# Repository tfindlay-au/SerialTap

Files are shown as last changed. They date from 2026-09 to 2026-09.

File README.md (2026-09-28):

# SerialTap

An open-hardware board that puts an appliance's 5 V serial service port on
Home Assistant. An ESP32-C3 with level translation, powered by the appliance
itself: one 4-wire cable carries 5 V, GND, TX and RX.

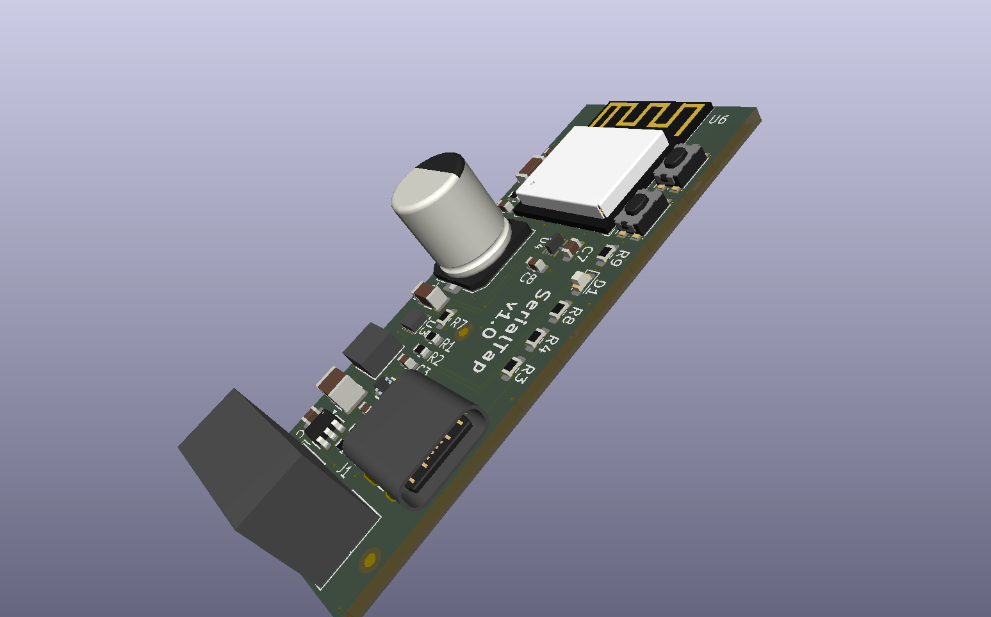
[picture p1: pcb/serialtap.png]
SerialTap v1.0, 3D render from KiCad


The reference target is a **Haier AS50QDFHRA** split-system air conditioner,
whose service port speaks GE Appliances **GEA3** at 230400 8N1
([docs/gea3.md](docs/gea3.md)). The board is not specialised to it: any
appliance exposing 5 V and a UART on a service connector is in scope.

## Status

**Version 1.0 has been sent to PCBWay; no board has been built yet.** The
`v1.0` tag marks the sources the order was built from.

Every design stage is done: power-path simulation, parts, library, schematic,
layout and three review gates. What is still owed is measurement on the real
appliance: the rail's current has so far been inferred, not measured
([ADR 0007](docs/adr/0007-rail-limit-inferred-not-measured.md)).

## The board

- **22 × 54 mm, 4-layer**, single-sided assembly, no mounting holes. It keeps
  the OEM module's outline and sits in its slot.
- **ESP32-C3-MINI-1** module. Programming and logs go over its built-in USB on
  a USB-C connector, so the appliance UART is never shared with logging.
- **Fixed-direction level translation** (TXU0204) between the 3.3 V module
  and the 5 V port, behind ESD protection and series resistors.
- **Power** from either the appliance or USB-C, ideal-diode OR-ed, through a
  current-limited eFuse and a 470 µF polymer bulk capacitor into a
  synchronous buck (TPS62162).

Service connector, as fitted to the reference appliance:

| Pin | 1 | 2 | 3 | 4 | 5 |
|---|---|---|---|---|---|
| Signal | 5 V | TX (board drives) | RX | spare (unknown) | GND |

## Where to start

| To understand… | Read |
|---|---|
| The vocabulary | [CONTEXT.md](CONTEXT.md) |
| The design, end to end | [docs/SPDD.md](docs/SPDD.md) |
| Why it is this way | [docs/adr/](docs/adr/): seven decisions, each with its context and what would reverse it |
| The protocol | [docs/gea3.md](docs/gea3.md) |
| How the schematic was checked | [docs/schematic-capture.md](docs/schematic-capture.md) |
| Layout rules and review gates | [docs/layout-rules.md](docs/layout-rules.md) |
| Parts and sourcing | [bom/README.md](bom/README.md) |
| Power-path simulation | [sim/README.md](sim/README.md) |
| Bring-up and measurement | [docs/bench-plan.md](docs/bench-plan.md), [docs/bench-results.md](docs/bench-results.md) |

## Repository layout

```
pcb/     KiCad 10 project: serialtap.kicad_sch / .kicad_pcb / .kicad_pro
lib/     the project's own symbols, footprints, 3D models and datasheets
sim/     LTspice power-path decks and their results
bom/     bill of materials and sourcing notes
docs/    design document, ADRs, protocol, layout and bench notes
bench/   capture and analysis scripts, and the ESPHome config used on the bench
```

## Opening and checking the design

Open `pcb/serialtap.kicad_pro` in **KiCad 10**. Everything it references is
in `lib/` through `${KIPRJMOD}`-relative paths, so it needs no global library.

```sh
CLI=/Applications/KiCad/KiCad.app/Contents/MacOS/kicad-cli   # macOS path
"$CLI" sch erc pcb/serialtap.kicad_sch
"$CLI" pcb drc --schematic-parity pcb/serialtap.kicad_pcb
```

The simulations need LTspice and vendor models that are not redistributed
here; [sim/README.md](sim/README.md) explains how to get them.

Fabrication outputs are regenerated rather than committed. Each fab order is
tagged, so a physical board traces back to its sources.

## Licence

Hardware under **CERN-OHL-P v2**; firmware and documentation under **MIT**.
Both are permissive. [NOTICE](NOTICE) sets out which files fall under which,
and the third-party material that falls under neither.

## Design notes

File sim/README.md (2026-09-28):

# Power-path simulation

Standalone LTspice decks, deliberately outside the KiCad flow
([SPDD §5.8](../docs/SPDD.md)). They model the **power path only**; nothing
else on the board has a usable model or a question worth simulating.

Simulation **gates fabrication** ([SPDD §12.1](../docs/SPDD.md) step 1). The
point is not a pass mark — it is a *number* to go and measure the appliance
against.

## Running

```sh
./models/fetch-models.sh   # once - vendor SPICE models (see below)
./run.py                   # every deck
./run.py rail-sag          # one deck
```

`run.py` drives `LTspice -b`, decodes the UTF-16 log it leaves behind, joins
each `.step` line to its `.meas` results and writes a table to
`results/<deck>.md`. Everything in `results/` is generated — re-run, never
edit. Stdlib Python only; no dependency outside this repo.

LTspice lives at `/Applications/LTspice.app/Contents/MacOS/LTspice`.

## The decks

| Deck | Question | State |
|---|---|---|
| `rail-sag.cir` | Given a current-limited source, bulk capacitance and WiFi transmit bursts, does the 5 V rail stay high enough for the buck to hold 3V3? | runs |
| `inrush.cir` | What does the appliance see at plug-in, with the eFuse limit set to a given value? | runs |
| `buck-load-step.cir` | Does the buck recover from a 40 → 335 mA step without undershooting brownout? | runs — **yes, with ~290 mV of margin** |

SPDD §5.4 quotes the step as 30 → 250 mA. Those are the **5 V-side** figures;
seen from the buck's output, where a load step actually happens, the same event
is 40 → 335 mA, which is what `buck-load-step` applies.

## The vendor models

### TPS62162 buck

`buck-load-step` is the one deck a behavioural block cannot answer — overshoot,
undershoot and settling belong to the control loop, the inductor and the output
capacitor together. It runs on TI's own model for the **TPS62162**.

`models/fetch-models.sh` downloads TI's *unencrypted* PSpice transient model
(literature number SLVMCV3) and converts it. Four things are worth knowing:

- **The vendor file is not committed.** TI ships it "as an aid for customers of
  Texas Instruments" with no redistribution grant, so the repo carries the fetch
  step and the converter instead of the file. This is the one exception to
  CLAUDE.md's "the project carries its own library" rule, and it is a licensing
  exception, not a convenience one — `lib/` still carries every KiCad asset.
- **One construct needed converting.** LTspice already understands PSpice's
  `VSWITCH` models, `TABLE {} = () ()` and `VALUE { IF(...) }` — all verified
  against this build before the converter was written. What defeats it is
  PSpice bracing a parameter reference *inside* a braced expression
  (`VALUE {{IF(V(A) > {VTHRESH}, {VDD},{VSS})}}`): the braces end up nested and
  LTspice reports "Questionable use of curly braces". `pspice2ltspice.py`
  strips the inner braces and passes everything else through untouched — 29
  expressions in this model.
- **`startup` on the `.tran` line is mandatory.** TI wrote the model for PSpice,
  which always solves an operating point first, so its internal latches and
  references need one. Plain `.tran` sends LTspice into minutes of Gmin
  stepping; `.tran ... uic` skips the operating point and the model sits dead,
  never switching. `startup` solves the operating point with the sources at
  zero — which converges immediately — then ramps them.
- **It is slow.** The model's soft-start runs about 1.5 ms and has to complete
  before a load step means anything, and a 2.2 MHz switcher is resolved
  throughout. Budget minutes per run and do not add sweeps casually. The `SS`
  subcircuit parameter looks like a way to skip soft-start — it is the initial
  condition on the ramp node — but setting it stops the model starting at all.
  Because a run is expensive, prefer `./run.py --keep-raw buck-load-step` when
  you might want to look at the waveform afterwards; the default throws the
  `.raw` away once the measurements are parsed out.

### Corrected result

Run 2026-09-20, on the TPS62162 model and Coilcraft's XGL4020-222 `_sat`
model, with no behavioural stand-ins in the power stage. The fixed-output
part's `FB` pin is tied to AGND, as required by the datasheet. This supersedes
the 2026-09-13 run, which left FB floating.

| COUT | regulated | undershoot on 40 → 335 mA | overshoot | margin to 3.0 V |
|---|---|---|---|---|
| 4.7 µF | 3.2994 V | 3.2846 V | 3.3107 V | **+285 mV** |
| 10 µF | 3.2994 V | 3.2905 V | 3.3099 V | +290 mV |
| 22 µF | 3.2994 V | 3.2926 V | 3.3074 V | +293 mV |

The corrected run passes with roughly 290 mV in hand at every capacitor value
tried.
Undershoot is 15 mV at worst — which is better than a 22 µF output capacitor on
a 295 mA step has any right to be, and implies the loop reacts within a switching
cycle or two. DCS-Control is genuinely that fast, but the model is TI's
behavioural one, so treat the absolute figure with suspicion. The conclusion
survives the doubt: the margin would have to be wrong by a factor of twenty
before this fails.

Going 22 µF → 4.7 µF costs 8 mV of
undershoot, so DC-bias derating cannot hurt us here: a 22 µF 0603 part that
derates to a third of its nameplate at 3.3 V still leaves the rail nowhere near
brownout. Size the output capacitor for ripple and stability, not for the load
step.

**The capacitor models in that deck are placeholders.** The converter is the
selected TPS62162 and the inductor is the selected XGL4020-222MEC. Re-run after
pinning the real input/output capacitor MPNs.

### PCL1A471MCL1GS bulk capacitor (C4)

`rail-sag` and `inrush` model C4 with **Nichicon's own model**, a 7-element RC
ladder (3.1 nH in series with three R–C branches totalling 475 µF). Nichicon's
engineering department supplied it on request with report FTR26-041,
2026-09-28. It replaced `CBULKX`, a lumped 470 µF with a flat 17 mΩ ESR.

- **Not committed, for the same reason as TI's.** It was sent to the project,
  not published for redistribution. `sim/.gitignore` already excludes
  `models/vendor/` and `models/*.lib`; `fetch-models.sh` documents the manual
  step and converts the CRLF line endings, which is the only conversion it
  needs — the model is plain L, R and C.
- **Checked against the datasheet before use**, by AC sweep:

  | | `CBULKX` (retired) | Nichicon model |
  |---|---|---|
  | \|Z\| at 120 Hz | 2.82 Ω | 2.79 Ω |
  | ESR at 100 kHz | 17 mΩ | **8.6 mΩ** |
  | ESR at 1 MHz | 17 mΩ | 7.7 mΩ |
  | Self-resonance | — | 159 kHz |

  The model's ESR is half the datasheet figure because 17 mΩ is the
  datasheet's *maximum*; the model is a typical part. So the old deck was
  conservative, not wrong. The model is small-signal, at 20 °C and 0 V bias;
  polymer capacitance barely moves with bias, so that is a fair basis.
- **It changes no result.** Run side by side on a 5 mA grid, the minimum
  appliance current is identical at every duty (110 / 170 / 245 mA), and
  `v5min` differs by at most 11 mV wherever both pass. Every `inrush` case
  passes or fails the same way. That is what the average-current finding below
  predicts: the capacitor's detail cannot move a number set by mean draw.
- **The decks run Gear integration because of it.** 3.1 nH over 6.6 mΩ is a
  ~0.5 ns time constant against a 10–20 µs step, and under LTspice's default
  trapezoidal method isolated steps came back with **all-zero measurements and
  no error in the log** — a false `NO` in the table. `method=gear` removes them
  and moves every other `v5min` by under 0.3 mV. If a row of zeros ever
  reappears, suspect the solver before the circuit.
- **The 220 µF / 1000 µF sweep was retired with `CBULKX`.** A vendor model is
  one part at one value. The sizing question it answered is settled below; the
  sweep is in git history if it is ever reopened.

## Model fidelity

`models/behavioral.lib` holds **behavioural** blocks, not vendor models. They
describe the terminal behaviour the datasheets promise over the timescales
these decks care about (~µs to ~1 s). Where a vendor model exists for the part
finally chosen, it replaces the block — as TI's has for the buck in
`buck-load-step`, and Nichicon's for C4 in `rail-sag` and `inrush`.

What they deliberately do not contain, and what therefore cannot be concluded
from these decks:

- **No switching.** The buck is a constant-power load, not a converter. Ripple,
  switching harmonics and EMI are not simulated here — EMC is
  `kicad-happy`'s job after layout.
- **No control loop.** The behavioural buck is a constant-power load with a
  UVLO, which is right for `rail-sag` and `inrush` and useless for a load-step
  question — hence `buck-load-step` running on the vendor model instead.
- **Instant limiter response.** `CLIM` reaches its limit in one timestep. A
  real TPS2553-class eFuse takes microseconds, so `inrush`'s `ispike` column
  understates the true contact event. Connector and cable inductance are not
  modelled either.
- **No temperature, no tolerance.** Every value is nominal at 27 °C. Tolerance
  is applied by hand when reading the results (see the eFuse arithmetic below).
- **Capacitance is a constant.** DC-bias derating is applied when choosing the
  parameter value (SPDD §7.1), not modelled as a function of voltage.

## What the decks found

Run 2026-09-12; **`rail-sag` and `inrush` re-run 2026-09-20** against the design
values in [SPDD §5.3](../docs/SPDD.md) — 470 µF bulk, ideal-diode OR, 0.95 Ω
total series resistance from appliance to rail.

> **Why they were re-run, and two defects found doing it.** Both decks were
> unrunnable in a clean checkout, so the tables below could not be reproduced.
>
> 1. `models/behavioral.lib` — which defines `CLIM`, `IDEALD`, `CBULKX` and
>    `BUCKLOAD`, every block `rail-sag` and `inrush` are built from — was
>    deleted by commit `786b8c3`, which moved `buck-load-step` onto vendor
>    models. The two behavioural decks still included it. `.gitignore` carries
>    an explicit `!/models/behavioral.lib` exception, so the deletion was
>    plainly accidental. Restored from history.
> 2. `rail-sag` set `RFUSE = 0.0` in commit `c5ce298` to record that no PTC is
>    fitted. **LTspice rejects a zero-ohm resistor outright**, so the deck has
>    been dead since 2026-09-13 and its committed results dated from *before*
>    the PTC was dropped. The parameter still reads 0.0 as the design
>    statement; the element is now `{max(RFUSE,1u)}`, and 1 µΩ is 0.25 µV at
>    250 mA.
>
> `ESRBULK` was also corrected from an assumed 25 mΩ to the **17 mΩ** the
> `PCL1A471MCL1GS` datasheet specifies at 100 kHz.
>
> **No conclusion reverses.** One cell of the table below moved, by 10 mA, and
> it strengthens the finding on bulk capacitance rather than weakening it. The
> 300–370 mA requirement is unchanged.

### The number: minimum appliance supply current

Minimum source current at which the 5 V rail stays above 4.0 V — the
placeholder for the buck's minimum input, `VBUCKREQ` in the deck:

| Radio duty | 220 µF | **470 µF** | 1000 µF |
|---|---|---|---|
| 20% — steady ESPHome traffic | 175 mA | **110 mA** | 110 mA |
| 50% — busy link | 200 mA | **175 mA** | 175 mA |
| 91% — association / OTA | 250 mA | **250 mA** | 250 mA |

**Sag is an average-current problem, not a peak-current one.** The knee sits
within ~10% of the mean draw in every case. Bulk capacitance rides out an
individual transmit burst; it cannot manufacture average current.

**And the answer barely depends on the buck.** `VBUCKREQ` is a reporting
threshold, not a modelling one, so the same results can be re-judged against a
different minimum input voltage without re-running. Dropping it from 4.0 V to
3.5 V — roughly dropout for the TPS62162 at this current, and well under any
candidate's UVLO — moves exactly one corner of the table (220 µF at 20% duty,
175 → 130 mA) and leaves every other figure unchanged. That is because the
failure mode is average-current starvation, which collapses the rail entirely
rather than dipping it marginally below a threshold. So the 300–370 mA
requirement stands whichever family member is finally chosen.

**This settles how much bulk is worth fitting.** Going 470 µF → 1000 µF buys
**nothing at any duty** — the two columns are now identical at every row.
Dropping to 220 µF costs 65 mA. 470 µF (SPDD §5.3) is the right size, and "add
more bulk" is *not* the answer if the Haier turns out marginal — more source
current is. (Before the 2026-09-20 corrections the 1000 µF column showed a
10 mA advantage at light duty; with the real capacitor's lower ESR that
advantage disappears.)

**Re-run 2026-09-28 on Nichicon's model for C4** (see "The vendor models"),
with the eFuse limit corrected to the fitted 400 mA (it read 600 mA) and
`inrush`'s `RFUSE` corrected to 0 Ω (it still carried the removed PTC's
0.2 Ω). The 470 µF column above is reproduced exactly — 110 / 175 / 250 mA —
and no `inrush` pass or fail moved. The 220 µF and 1000 µF columns are from the
retired lumped-capacitor sweep.

### The eFuse limit

`inrush` is unambiguous: the eFuse limit must sit **strictly below** the
appliance's own limit. Above it, the appliance is driven into its own current
limit and its rail is dragged down to follow the charging capacitor for the
whole ramp — 8–17 ms of an undefined state that may reset the appliance, which
is the failure [ADR 0004](../docs/adr/0004-current-limited-inrush.md) exists to
prevent.

Ramp time is just Q/I: 9.5 ms at 250 mA into 497 µF (C4's 475 µF plus the
ceramics), and the appliance is asked for a flat current for that whole time —
no peak beyond the limit itself.

`inrush` now also steps the **fitted** limit — `RILIM` = 66.5 kΩ, 351 / 400 /
449 mA across its tolerance. All three are polite to a 500 mA rail and none to
a 300 mA one, which is the rule above applied to the real part: this board
assumes the rail sources more than 449 mA. That is
[ADR 0007](../docs/adr/0007-rail-limit-inferred-not-measured.md)'s inference
from the ~590 mA the OEM module drew, not a new finding, and it is what the
series current measurement at bring-up will test.

Sizing, with `TOL` the chosen part's current-limit accuracy:

```
IEF_nom  ≥  sustained average draw / (1 - TOL)     so it never limits in service
IEF_nom  ≤  appliance limit / (1 + TOL)            so it always limits before
                                                    the appliance does
```

Taking the 246 mA sustained-transmit average from `rail-sag`:

| Limit accuracy | IEF nominal | Appliance must supply |
|---|---|---|
| ±10% | ≥ 273 mA | > 300 mA |
| ±20% | ≥ 308 mA | > 370 mA |

Which is the real headline: **the appliance needs 300–370 mA, not 250 mA**, if
the board is to both survive sustained transmit and stay polite at plug-in. The
figure firms up once the eFuse MPN — and with it `TOL` — is chosen.

### What to measure on the Haier

[SPDD §12.1 step 2](../docs/SPDD.md) now has numbers to test against:

1. Open-circuit voltage of the 5 V service rail.
2. **Current limit** — the one that matters. Pass is ≥ 370 mA; 250–300 mA means
   OTA and association on appliance power are at risk and the eFuse must be set
   below whatever the rail actually gives; under 250 mA the design needs
   rethinking, and not by adding capacitors.
3. Sag under a 250 mA pulsed load, to get `RAPP` — currently a 0.5 Ω guess.
4. Behaviour *in* current limit: does it fold back, latch off, or reset the
   appliance? The decks assume it merely droops.

## Parameters worth revisiting

| Parameter | Current value | Why it is a guess |
|---|---|---|
| `RAPP` | 0.5 Ω | Appliance source impedance. Measurement, item 3 above. |
| `RCABLE` | 0.25 Ω | ~1 m of 26 AWG out and back. Depends on the harness finally built. |
| `VBUCKREQ` | 4.0 V | Placeholder for the buck's minimum input. `margin` is `v5min - VBUCKREQ`, so results can be re-judged without re-running. |
| `RFUSE` | 0 Ω | No PTC is fitted; TPS2553 supplies the selected input protection. The deck represents 0 Ω as 1 µΩ because LTspice rejects an ideal zero-ohm resistor. |
| `TON` / duty | 2 ms, 20–91% | Transmit burst shape. Worst case is asserted, not measured. Worth a current probe during bring-up. |

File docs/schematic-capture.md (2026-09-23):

# Schematic capture contract — SerialTap

This is the wiring target for `pcb/serialtap.kicad_sch`. It records the
settled connectivity so schematic capture is a transcription and review task,
not another architecture discussion.

## Connector roles

J1 is the board-mounted JST XA service connector. The labels are from the
board's point of view:

| J1 pin | Net | Function |
|---:|---|---|
| 1 | `PORT_5V` | appliance 5 V input |
| 2 | `PORT_TX` | board output to appliance — the appliance's receiver |
| 3 | `PORT_RX` | appliance output to board — the appliance's transmitter |
| 4 | `PORT_NC` | deliberately unconnected until the harness investigation assigns it |
| 5 | `GND` | common return |

**Corrected 2026-09-20.** This table originally read 5 V, GND, TX, RX, spare at
pins 1–5, from a connector that was being read from the wrong end. Old pin *n*
is new pin *6 − n*. Direction is settled by the working TinyS3 rig, not
inferred: TinyS3 TX drives pin 2, pin 3 drives TinyS3 RX
([gea3.md](gea3.md)).

J2 is USB-C. All VBUS pins join `USB_VBUS`; all GND pins and shield join
`GND`; D+ and D− go through the USB ESD array to C3 GPIO19 and GPIO18.
CC1 and CC2 each receive a 5.1 kΩ pulldown to GND.

## Power tree

```text
PORT_5V ── TPS2553 IN
             TPS2553 OUT ── LM66200 IN1
USB_VBUS ────────────────── LM66200 IN2
                              LM66200 OUT ── V5
V5 ── TXU VCCB, bulk capacitor, buck VIN, power LED
TPS62162 VOUT ── V3V3 ── C3 VDD, TXU VCCA
```

TPS2553 `EN` is tied high to its input supply so the appliance branch is always
enabled. `FAULT` is brought to a labelled test pad or left as an explicitly
marked no-connect; `ILIM` receives the selected resistor to GND. There is no
PTC/resettable fuse. LM66200 provides the source isolation and TPS2553 provides
the port current limit and reverse blocking.

TPS62162 support wiring is fixed:

- `FB` → `AGND`
- `VOS` → `V3V3` at the output-capacitor positive terminal
- `AGND`, `PGND`, and exposed pad → `GND`
- `EN` → `V5`
- `PG` → labelled test pad (or explicit no-connect if not used by firmware)
- `SW` → XGL4020-222MEC → `V3V3`
- 10 µF ceramic from VIN to GND, 22 µF ceramic from V3V3 to GND, plus the 470 µF bulk on V5

## UART translation

The selected TXU0204RUTR is used as follows:

| TXU pin/function | Net |
|---|---|
| VCCA | `V3V3` |
| VCCB | `V5` |
| OE | `V3V3` |
| A1 input | C3 UART TX |
| B1Y output | `PORT_TX` through 330 Ω, 1% |
| B3 input | `PORT_RX` through 330 Ω, 1% |
| A3Y output | C3 UART RX |
| A2 and B4 inputs | tied to GND |
| A4Y and B2Y outputs | no-connect |
| GND and exposed pad | GND |

The TPD4E05U06QDQARQ1 channels are assigned to `PORT_TX`, `PORT_RX`, USB D+,
and USB D−. Its ground pin connects directly to GND. Each connector-facing
line reaches its ESD channel before the UART series resistor or USB trace.

## C3 support and recovery

- GPIO18 → USB D−; GPIO19 → USB D+
- GPIO9 has a 10 kΩ pull-up to V3V3 and BOOT switch to GND
- EN has a 10 kΩ pull-up to V3V3, RESET switch to GND, and reset capacitor to GND
- C3 receives local 100 nF and 10 µF V3V3 decoupling
- UART1 uses GPIO4 as TX and GPIO5 as RX; these are assigned to the TXU A-side nets

## Review invariants

- J1 pin 4 has no copper connection other than its own pad.
- No USB VBUS path can reach `PORT_5V` except through the LM66200 ideal-diode OR.
- The ESD array is ahead of both UART series resistors.
- `FB` is not floating; `VOS` senses at the output capacitor.
- Every unused TXU input is tied off and every unused output is explicitly no-connect.
- Every passive has an MPN before ERC/BOM review; values above are design values, not distributor substitutions.

## Capture record — 2026-09-20

Captured into [`pcb/serialtap.kicad_sch`](../pcb/serialtap.kicad_sch),
KiCad 10 native format (`version 20260306`), one A3 sheet in seven labelled
blocks: service port, USB-C, power path, level translation, ESP32-C3, test
access, ERC power sources. **43 components, 57 nets.**

`kicad-cli sch erc --severity-all` reports **0 violations**.

The connectivity above was transcribed and then checked against the *extracted
netlist*, not against the drawing — a drawing can look right and still be
wrong. Every review invariant, as `kicad-cli sch export netlist` reports it:

| Invariant | Netlist evidence |
|---|---|
| J1 pin 4 has no copper other than its own pad | `unconnected-(J1-Pin_4-Pad4)`, one node |
| No USB VBUS path to `PORT_5V` except through the OR | `USB_VBUS` = J2 VBUS ×4, C3, U2.VIN2. `PORT_5V` = J1.1, U1.IN, U1.EN, C1. They meet only at U2's output |
| ESD array ahead of both UART series resistors | `PORT_TX` = J1.2, **U5.D2+**, R1.1 — and `TX_BUF` = R1.2, U4.B1Y, TP4. Same shape for RX |
| `FB` not floating; `VOS` senses at the output capacitor | U3.5 (`FB`) is in `GND`; U3.6 (`VOS`) is in `V3V3` with C6 |
| Every unused translator pin handled | A2, B4 tied to `GND`; A4Y, B2Y carry explicit no-connects |
| Every passive has an MPN | **Not met** — see "Still open" below |

### Decisions taken at capture

- **`RILIM` = 66.5 kΩ 1% (R5).** TI's Table 2 row for a 400 mA nominal limit;
  with part and resistor tolerance the limit lands **351–449 mA**. That is
  ~100 mA above the board's 250 mA worst-case 5 V draw, so a Wi-Fi TX burst
  cannot nuisance-trip it, and below the ~590 mA inrush the rail demonstrably
  sources for the OEM module it was built to feed
  ([ADR 0007](adr/0007-rail-limit-inferred-not-measured.md)). The 88.7 kΩ /
  300 mA alternative was rejected: its 262 mA minimum leaves only 12 mA over
  the board's own estimated peak. Still an inferred value, to be confirmed at
  bring-up.
- **`FAULT`, `PG` and `ST` go to test pads** (TP8, TP9, TP10), not to GPIOs.
  Zero BOM cost, no firmware coupling. `FAULT` and `PG` are open-drain and
  carry pull-ups (R6 to `V5`, R7 to `V3V3`). The cost is that neither fault
  state is visible to Home Assistant; routing them to GPIO6/GPIO7 later is a
  respin, so this is the decision to revisit if remote fault reporting matters.
- **Drawing style: rails and cross-block signals by symbol and label, local
  topology by wire.** Power symbols (`PORT_5V`, `USB_VBUS`, `V5`, `V3V3`,
  `GND`) carry the rails; labels carry signals between blocks; wires are drawn
  where the topology is the point — the J1 → ESD → series resistor chain, the
  buck's SW node through L1, the BOOT and RESET networks, each pull-up. This
  keeps a 43-part board on one readable sheet. The netlist, not the drawing, is
  what was checked.
- **`LM66200` `VOUT_2` pin type changed to passive** in the project library.
  `VOUT_1` and `VOUT_2` are the same internal node, and two `power_out` pins on
  one net is an ERC conflict. The datasheet I/O column still says output; the
  library note records why the symbol departs from it.
- **Eleven generic symbols added to the project library** (R, C, LED, SW_Push,
  TestPoint, PWR_FLAG, GND, V5, V3V3, PORT_5V, USB_VBUS), copied from KiCad 10's
  own libraries so nothing references outside the repo. See
  [lib/README.md](../lib/README.md).

### Review gate 1 — kicad-happy, 2026-09-20

Run on the schematic alone; no PCB exists yet, so the cross-domain, EMC,
thermal and gerber analyses were **not run** and neither was the lifecycle
audit. 28 findings: 2 errors, 2 warnings, 24 informational.

| Finding | Verdict |
|---|---|
| `PP-001` U2.VIN1 has no DC path to a rail | **False positive.** `EFUSE_OUT` holds U1.OUT (`power_out`), U2.VIN1 and C2. The DC path runs through U1's pass FET; the rule walks the net graph only and cannot traverse an IC. A current-limited switch between two rails always trips it |
| `SS-001` BOM under 50% MPN coverage (9/21) | **True, and expected.** The passives are the open gate below |
| `DS-002` no `datasheets/` directory | **Path convention.** This project keeps vendor PDFs in `lib/datasheets/` beside the symbols that cite them |
| `UC-002` no ESD/TVS on VBUS at J2 | **Genuine, and accepted — not fitted** (decided 2026-09-20; see below and open item 2) |
| `PR-004` no series resistors on USB D+/D− | **Expected.** The C3's USB Serial/JTAG PHY needs none; Espressif's own boards fit none |

**The VBUS finding is worth a decision.** All four ESD channels are committed
(`PORT_TX`, `PORT_RX`, USB D+, D−), so VBUS is unprotected. `PORT_5V` is
covered by a different mechanism — the TPS2553 is rated 15 kV IEC 61000-4-2
*with external capacitance*, which C1 provides. VBUS has no equivalent: it
reaches the LM66200 directly, whose inputs are **6 V absolute maximum**
(datasheet §6.1) against a hot-plug transient that can overshoot well past
5.5 V. C3 (1 µF) damps it; nothing clamps it. A single-channel TVS on VBUS
would close this. Not fitted, because it is a new part and this project pins
parts deliberately rather than by reflex.

**Decided 2026-09-20, not to be reopened:** USB is used once, to flash the
board at setup — closer to a Tag-Connect pogo header than to a cabled port. The
risk is carried knowingly; see open item 2 below.

### Amended 2026-09-20: J1 pin numbering corrected

Captured first against the original table, then rewired when the connector was
found to have been read from the wrong end. The board-side nets are unchanged
— `PORT_TX` is still what the board drives — but they move pads: J1.2 now
carries `PORT_TX` through R1, J1.3 carries `PORT_RX` through R2, J1.4 is the
no-connect and J1.5 is ground. Confirmed in the netlist:

```
PORT_5V    J1.1 + C1.1 U1.1 U1.3
PORT_TX    J1.2 + R1.1 U5.4          TX_BUF  R1.2 + U4.10 (B1Y, output)
PORT_RX    J1.3 + R2.1 U5.5          RX_BUF  R2.2 + U4.8  (B3,  input)
unconnected-(J1-Pin_4-Pad4)
GND        J1.5 + ...
```

`TX_BUF` lands on the translator's B-side **output** and `RX_BUF` on its
B-side **input**, so the direction through the fixed-direction buffer matches
the rig that works.

### Amended 2026-09-21: TVS channels swapped for layout

`U5`'s four channels are identical, so which pair carries UART and which
carries USB is a layout choice, not an electrical one. With the array placed
under the USB-C pin row and the D± pair arriving from the module on the left,
the pair has to enter the **top** two pads or its descent crosses the UART
exits on L1. The labels were therefore swapped: **pins 1/2 (`D1±`) now carry
`USB_DP`/`USB_DM`, pins 4/5 (`D2±`) carry `PORT_TX`/`PORT_RX`.** The netlist
tables above are updated to match; ERC remains at 0 violations. No BOM change.

### Still open after capture

1. ~~**Passive MPNs.**~~ **Done 2026-09-20**, switches included — see
   [bom/README.md](../bom/README.md) and SPDD §7.4. Two capture defects surfaced
   while pinning them, both fixed: **C4 had been drawn with the generic `C`
   symbol** instead of its own `PCL1A471MCL1GS` symbol, which cost it an MPN, a
   footprint and — on a polarised polymer capacitor — its polarity marking; and
   **the ten test pads were appearing as a BOM line**, now excluded from the BOM
   while staying on the board as copper. Pinning the switches then changed a
   third thing: **R9 is 2.2 kΩ, not 10 kΩ**, so SW1's contacts carry 1.5 mA
   against C&K's 1 mA minimum (SPDD §7.4). R10 stays 10 kΩ.
2. ~~**VBUS TVS**~~ **Accepted, not fitted** (2026-09-20). The USB port is a
   one-off setup interface — the operational path is J1 — so the exposure is
   closer to a debug header's than to a permanently cabled port. The risk is
   real and recorded; the decision is to carry it.
3. **Reference designators are functional, not positional.** Re-annotate in
   KiCad if left-to-right ordering matters for the assembly drawing.

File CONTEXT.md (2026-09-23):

# Context: SerialTap

## What this project is

**SerialTap** is an open-hardware board that puts an appliance's 5 V serial
service port on Home Assistant. An ESP32 module plus bidirectional level
translation, powered by the appliance itself — one 4-wire cable carries 5 V,
GND, TX and RX.

Primarily a hardware design project: schematic and layout (KiCad 10),
gerbers, BOM, CPL and an assembly package for PCBWay. Scope also includes the
ESPHome package that runs on the returned boards and documented cable pinouts
per appliance, so that someone else can build one and fit it.

## Design principles

**1. Quality over cost.** This is not a race to the bottom on part count or
price. Where a branded part yields a better product, use it. Where extra
decoupling makes the circuit work better, add it. BOM cost on a five-board run
is dwarfed by assembly setup, shipping and time — and a marginal part that
forces one respin costs more than it ever saved.

Concretely: polymer or hybrid aluminium for bulk rather than generic
electrolytic; MLCCs chosen with DC-bias derating in mind, not just nameplate
capacitance; a shielded branded inductor with real saturation margin; genuine
JST parts, not clones.

**2. The design is not limited to KiCad's stock libraries.** Parts are chosen
for the design, and their symbols, footprints and 3D models are sourced from
SnapEDA or elsewhere as needed.

**3. The project carries its own library.** Everything the design depends on
lives in the repo, referenced with `${KIPRJMOD}`-relative paths, so the next
person can open it without having this machine's global library.

## Glossary

### SerialTap
The project and the board. Named for what it does: it taps an appliance's 5 V
serial service connector for **both data and power** over a single 4-wire cable.

Deliberately neutral about silicon and vendor — the module already changed once
mid-design (S3 → C3) and the reference appliance is only the first of many.

Previously named `esp32leveler`, where "leveler" meant *logic level translator*
and was routinely misread as a spirit level or inclinometer. That name is
retired; any surviving reference to it means this project.

### Level translator
The circuit that converts between the ESP32's 3.3 V logic and the target's 5 V
logic. Informally "level shifter"; use **translator** in schematic and doc text.
Never "leveler".

### Target device
The external equipment the board talks to over UART. It drives 5 V logic levels
and is the reason level translation exists at all.

### Board
The physical PCB design: the files `pcb/serialtap.kicad_*`. It has no revision
in its name — its version is a git commit, and a fab order is tagged so a board
in hand traces back to the commit it was built from.

### Port
The board's single level-translated UART channel, translated in both directions
with fixed-direction buffers.

Physically a **5-pin** JST XA connector (2.5 mm pitch), of which the design
uses four, in order **5 V, TX, RX, spare, GND**. It is simultaneously the data path to the
target device and the board's primary power source. There is exactly one port:
the board is a single-target adapter, not a multi-port gateway.

Five pins because that is what the reference target has. Confirmed 2026-09-12
on the AS50QDFHRA, mated with a JST **XARR-05V** panel housing — XA series,
2.5 mm pitch, contacts sold separately. The board therefore carries a 5-pin XA
header so the harness can be straight-through, which is the least error-prone
cable to build and to get wrong.

**What pin 4 does is unknown.** It read as floating on the capture — no
contact, or a genuine spare. Until that is settled it connects to nothing on
the board — not the ESD array, not a GPIO — because strapping an unknown signal
to a net that matters is a worse failure than losing a pin.

**The numbering was corrected on 2026-09-20**, having previously been read from
the wrong end of the connector: old pin *n* is new pin *6 − n*. Every document
in this repo now uses the corrected numbers.

### Primary supply
The 5 V arriving on the port's JST XA connector. The board is normally powered by
the target device it is controlling.

### Supply sources
Two, either of which may be live: the port's JST XA (primary) and USB-C (bench).
They are OR-ed with ideal diodes so neither can back-feed the other — in
particular so a laptop's USB cannot push 5 V into the target appliance's rail.

### Bench access
USB-C only. It carries first flashing (esptool over the C3's ROM USB
Serial/JTAG), ESPHome console logging over USB CDC, and OpenOCD debug. In
normal service the board is updated by ESPHome OTA and USB-C is unused.

### Recovery
BOOT (GPIO9) and RESET (EN) tact switches. Not needed for ordinary flashing —
esptool resets the chip into download mode over USB by itself — but the only
way back if firmware repurposes the USB pins, wedges the USB peripheral, or
boot-loops.

### Reference target
**Haier AS50QDFHRA** split-system HVAC. It speaks **GE Appliances GEA3** over
UART at 230400 8N1 — confirmed two-way on 2026-09-19 with an ESP32 running
the esphome-gea component, which returned 64 ERDs. It does *not* speak Haier
hOn or smartAir2, and ESPHome's built-in `haier` component does not apply.
The SPDD's firmware scope predates this and needs an ADR. See
[docs/gea3.md](docs/gea3.md).

It is the *reference* target, not the only one: it is what the first boards are
validated against and what the connector pinout is chosen to match.

### Generic use
The board is intended to work with any appliance exposing 5 V power and UART on
a service connector. Nothing in the hardware may assume Haier specifically — no
protocol-dependent circuitry, no reliance on a particular idle level, and no
assumption about how much current the appliance's 5 V rail can supply.

### Port pinout
Fixed, not selectable. Conventional order **5 V, GND, TX, RX**, silkscreened
from the *board's* point of view: TX is the pin the board drives, RX is the pin
the board listens on.

There is no crossover jumper. Because the translators are fixed-direction
(see ADR 0001), a polarity mistake cannot be corrected in firmware either —
remapping the C3's UART pins would drive a buffer backwards. Adapting to an
appliance that orders or labels its pins differently is a **cable** problem, and
each appliance gets a documented harness.

## Resolved design decisions

| Area | Decision |
|---|---|
| Module | ESP32-C3-MINI-1 (ADR 0002) |
| Port | One, JST XA **5-pin**, four used: 5 V, TX, RX, (spare), GND |
| Translation | Fixed-direction dual-supply buffers (ADR 0001) |
| Supply sources | JST XA 5 V (primary) and USB-C, ideal-diode OR-ed |
| Inrush / sag | Current-limited eFuse + ≥470 µF low-ESR bulk (ADR 0004) |
| 3.3 V rail | Synchronous buck, not an LDO (ADR 0003) |
| Port protection | Series resistors on TX/RX; one quad ESD array protects both UART lines and USB D+/D−; TPS2553 protects the port 5 V input |
| Programming | USB-C only; BOOT (GPIO9) and RESET (EN) tact switches |
| Source of truth | KiCad 10 schematic → netlist → PCB (ADR 0005) |
| Parts | Every component pinned by MPN; no automatic part picking |
| Library | Project-local `lib/`, `${KIPRJMOD}`-relative, nothing global |
| Mechanical | Bare board, mounting holes, no enclosure |
| Stackup | 4-layer: L1 sig+parts / L2 GND / L3 rails / L4 GND |
| Outline | 22 × 54 mm; JST on one short edge, USB-C on the adjacent long edge, antenna at the far short edge |
| Fab class | PCBWay 5/5 mil, 0.2 mm drill (0.25 mm until 2026-09-24); impedance not controlled |
| Indicators | Power LED only; no status or activity LEDs |
| Test points | Pads on 5 V, 3V3, GND, and both sides of each translator channel |
| First run | 5 boards, single-sided assembly (all parts on top) |
| Scope | Hardware + ESPHome package + harness documentation |
| Licence | CERN-OHL-P for hardware, MIT for firmware and docs |
| Simulation | Power path only, LTspice decks in `sim/`, gates fabrication |
| Board acceptance | Loopback plug + ESPHome self-test, per board |

### Hot loop
The buck's input loop — input ceramic → high-side FET → low-side FET → ground →
back to the ceramic. It carries the fastest di/dt on the board and is the
dominant EMI source. Minimising its area outranks every other layout
consideration except the antenna keepout.

Distinct from the **switch node**, which is the dV/dt aggressor and is
deliberately kept small in *area* rather than poured.

### Project library
`lib/` at the repo root: symbols, footprints and 3D models for every part in the
design, plus datasheets. Referenced by the KiCad project in `pcb/` with
`${KIPRJMOD}`-relative paths.

Nothing in the design may depend on a library outside this directory.

### Simulation deck
A standalone LTspice netlist in `sim/`, hand-written and deliberately outside
the KiCad flow. Decks model the power path only; nothing else
on the board has a usable model or a question worth simulating.

### Loopback plug
A JST XA shell with TX bridged to RX. Turns the whole signal chain into a
self-test: firmware transmits a pattern and checks it returns, exercising both
translation directions, both series resistors and the connector, with no scope
and no appliance. It does not prove drive strength into a loaded line.

### Build artifact
Anything produced by `kicad-cli` from the design files: gerbers, drill files,
the BOM and CPL, the schematic PDF, STEP and image renders. These live under
`pcb/fab/` (gitignored until release) and are never hand-edited — regenerate them instead.

The design files themselves — `.kicad_sch`, `.kicad_pcb`, `.kicad_pro` — are
**not** build artifacts. They are drawn and maintained by hand, and they are the
source of truth (ADR 0005). Nothing generates them, which is why there is no
rule against editing them.

## Known risks

- **Weak appliance rail.** The Haier 5 V service output is current-limited and
  its capability is not yet measured. Mitigated by the buck (≈250 mA peak draw
  versus ≈335 mA for an LDO), soft start, and bulk capacitance — but the actual rail must be
  measured during bring-up before the design is considered validated.
  Simulation (`sim/`, 2026-09-12) says it needs to supply **300–370 mA**, and
  that bulk capacitance cannot substitute for source current: sag is set by the
  *average* draw, so the capacitor rides out one transmit burst and nothing
  longer.
- **Bare board in an appliance.** No enclosure means exposed electronics near
  HVAC condensate and mains wiring. Accepted deliberately; the board is not
  weather- or touch-protected, and any production use would need one.
- **No SPICE model for the buck or eFuse.** Simulation gates fabrication, so a
  part without a usable vendor model cannot be used regardless of price or
  availability. This constrains selection before a part is committed.
- **Silent substitution at assembly.** Every part is pinned by MPN precisely so
  that a cheaper equivalent cannot reach the board unnoticed. Substitutions must
  be proposed back for a decision, never applied silently.
- **Protocol — resolved.** The port speaks GEA3, which GE publishes
  (tiny-gea-api) and for which an ESPHome component exists (esphome-gea).
  Decoded 2026-09-18, confirmed two-way 2026-09-19, recorded in
  [ADR 0006](docs/adr/0006-gea3-not-hon.md) with the ERD map in
  [docs/gea3.md](docs/gea3.md). No hardware consequence; it *validates*
  ADR 0001, because GEA3 is full duplex with a fixed direction per line.
  Remaining work is firmware only: which ERD carries which control, the ten
  ERDs GE's public set does not name, and ERD `0x6003`.
- **Rail capability — inferred, not measured.** The resistor load test no longer
  gates fabrication; `RILIM` is set from inference instead
  ([ADR 0007](docs/adr/0007-rail-limit-inferred-not-measured.md)). What that
  gives up is written down there, along with the conditions that reinstate the
  test. The unexplained manual reset on first power-up from the rail is the one
  open item that could still change the design.
- **Unverified Haier pinout.** ~~Partly resolved.~~ **Resolved 2026-09-20,
  except for one pin.** The *connector* was confirmed on 2026-09-12: a 5-pin
  JST XA, 2.5 mm pitch, mated with an XARR-05V panel housing. The *pin order*
  is now settled — 5 V, TX, RX, spare, GND — after the numbering was found to
  have been read from the wrong end; direction comes from the working TinyS3
  link rather than inference. **Pin 4's function remains unknown**, which holds
  up nothing but the harness documentation.

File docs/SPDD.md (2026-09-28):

# Software & Product Design Document — SerialTap

**Status:** draft, pre-schematic
**Date:** 2026-09-12
**Licence:** CERN-OHL-P v2 (hardware), MIT (firmware and documentation)

Terminology for this project is defined in [CONTEXT.md](../CONTEXT.md).
Decisions with lasting consequences are recorded in [docs/adr/](adr/).

---

## 1. Purpose

A small PCB that lets an ESP32 speak UART to appliances whose serial ports use
5 V logic, and be powered by those same appliances over the same connector.

The immediate motivation is putting a **Haier AS50QDFHRA** split-system HVAC on
Home Assistant via ESPHome's `haier` component. The board is deliberately not
specialised to it: any appliance exposing 5 V, GND, TX and RX on a service
connector is in scope.

The name describes the mechanism: one 4-wire cable **taps** the appliance's
service connector for both data and power. It is deliberately neutral about
silicon and vendor — the module changed once during design and the reference
appliance is only the first of many.

Formerly `esp32leveler`, where "leveler" meant *level translator* and was
consistently misread as a spirit level.

## 2. Scope

**In scope**

- Schematic and PCB design (KiCad 10)
- Fabrication and assembly package for PCBWay: gerbers, drill, BOM, CPL
- A firmware package that runs on the assembled board, ESPHome by default
- Harness documentation: cable pinouts per appliance, starting with the Haier

**Out of scope**

- Any enclosure. The board ships bare (§8).
- Reverse engineering an appliance protocol from scratch. The reference
  appliance speaks **GEA3**, which is public and has both a portable C library
  and an existing ESPHome component ([ADR 0006](adr/0006-gea3-not-hon.md)).
  Mapping which ERD carries which control is observation, and is in scope.
- Certification, EMC testing, or commercial production

## 3. Functional requirements

| # | Requirement |
|---|---|
| FR-1 | Provide one bidirectionally level-translated UART channel between the ESP32's 3.3 V logic and a target's 5 V logic |
| FR-2 | Accept 5 V from the target on the same connector as the data lines, and run the whole board from it |
| FR-3 | Operate reliably at 230400 8N1 (the reference target's measured rate, [ADR 0006](adr/0006-gea3-not-hon.md)) and impose no design ceiling below 1 Mbaud |
| FR-4 | Be flashable from a bare, unprogrammed state over USB-C with no jig or external adapter |
| FR-5 | Be recoverable by hand if firmware renders USB unusable |
| FR-6 | Never source current into a target appliance's rail from a bench supply, or vice versa |
| FR-7 | Survive ordinary installation faults on the port: ESD, hot-plug, a line shorted to 5 V or GND |
| FR-8 | Support ESPHome OTA as the normal update path once first-flashed |

## 4. Architecture

**Signal path**

```
  JST XA          ESD    series R  fixed-direction        ESP32-C3-MINI-1
  TX ------------[ ]-----[ Rs ]---[ B->A translator ]----> RX  (UART1)
  RX ------------[ ]-----[ Rs ]<--[ A->B translator ]----- TX  (UART1)
                                  VCCB=5V  VCCA=3V3

                                   USB-C  D+/D- <-------> GPIO18/19
                                                  (ROM USB Serial/JTAG:
                                                   flashing, CDC log, debug)
```

**Power path**

```
  JST XA 5V ---------[ eFuse ]--[ideal diode]--+
                    (current-limited, bounds inrush) |
                                                +-- 5V rail --+-- [470uF+]
  USB-C VBUS ---------------------[ideal diode]-+              |
                                                               +-- [PWR LED]
                                                               |
                                                               +-- VCCB
                                                               |
                                                        +------+------+
                                                        | sync buck   |
                                                        |  5V -> 3V3  |
                                                        +------+------+
                                                               |
                                                        3V3 rail --> C3, VCCA
```

**Signal path.** Target ↔ ESD array ↔ series resistors ↔ fixed-direction
translators ↔ C3 UART1. Console and debug ride the C3's built-in USB
Serial/JTAG on GPIO18/19, out to USB-C, so the port's UART is never shared with
logging.

**Power path.** The JST 5 V and USB-C VBUS are each ideal-diode OR-ed onto a
common 5 V rail; a current-limited eFuse limits inrush; a synchronous buck
produces 3.3 V.

## 5. Detailed design

### 5.1 Level translation

Two fixed-direction dual-supply buffer channels — one 3.3 V → 5 V for TX, one
5 V → 3.3 V for RX — with direction hard-wired in copper. Rationale and the
rejection of auto-direction parts (TXB/TXS) is in
[ADR 0001](adr/0001-fixed-direction-level-translation.md).

VCCA is the 3.3 V rail; VCCB is the 5 V rail. Unused translator inputs are tied
off, never left floating.

Consequence to keep in mind: direction is frozen. Half-duplex or single-wire
buses are out of reach for this board without a revision.

### 5.2 Port and pinout

One JST XA **5-pin** connector (2.5 mm pitch), four of which are used, in fixed
pin order **1 = 5 V, 2 = TX, 3 = RX, 4 = spare, 5 = GND**, silkscreened from
the board's point of view — TX is the pin the board drives, which is the
appliance's receiver.

**This order is corrected as of 2026-09-20.** Earlier revisions of this
document, the bench notes and `gea3.md` numbered the connector from the wrong
end and read 5 V, GND, TX, RX at pins 1–4. Nothing measured changed; the
labels did. Direction is not inferred: on the working TinyS3 rig the shifter
carries TinyS3 TX into pin 2 and pin 3 into TinyS3 RX
([gea3.md](gea3.md)).

The pin count follows the reference target: the AS50QDFHRA service connector
was confirmed on 2026-09-12 to be a 5-pin XA, mated with a JST XARR-05V panel
housing. Carrying five on the board keeps the harness straight-through.

Board-side candidates, all XA series, 2.5 mm pitch, 5 position:

| MPN | Entry |
|---|---|
| `B05B-XASK-1(LF)(SN)` | vertical, top entry, shrouded |
| `B05B-XASK-1-A(LF)(SN)` | vertical, with locating boss |
| `S05B-XASK-1(LF)(SN)` | right angle, side entry |

Not yet pinned: entry direction is a mechanical call about how the board sits in
the appliance, and the gender/mating relationship against XARR-05V should be
read off the JST XA datasheet rather than a distributor summary before an MPN
is committed.

**Pin 4's function is unknown** — it read as floating, either no contact or a
genuine spare — so nothing on the board connects to it: not the ESD array, not
a GPIO. Committing it to anything before it is known risks strapping an unknown
signal, possibly not a 5 V-logic one, to a net that matters.

There is no crossover jumper, and the C3's GPIO matrix cannot substitute for
one: remapping UART pins would drive a fixed-direction buffer backwards.
Appliances that order or label their pins differently are accommodated by a
**cable**, documented per appliance.

### 5.3 Power

| Element | Choice |
|---|---|
| Sources | JST XA 5 V (primary), USB-C VBUS (bench) |
| Arbitration | Ideal-diode OR on each source (LM66100 / MAX40203 class) |
| Inrush | Current-limited switch / eFuse (TPS2553 class), programmable limit ([ADR 0004](adr/0004-current-limited-inrush.md)) |
| Bulk | ≥470 µF low-ESR on the 5 V rail, plus local ceramics |
| 3.3 V | Synchronous buck ([ADR 0003](adr/0003-buck-not-ldo.md)) |
| Fusing | **None.** TPS2553 provides constant-current limiting, thermal shutdown and reverse blocking, which is stronger and faster than a PTC's thermal trip. A PTC would only add cover for the eFuse itself failing short, and would cost 0.2–0.5 Ω in series — ~75 mV at 250 mA on a rail with no headroom to spare. Recorded as a deliberate removal, not an omission (ADR 0004 anticipated this) |

Ideal diodes rather than Schottkys because ~20 mV of drop keeps the 5 V rail
genuinely at 5 V for the translators' VCCB, and because a laptop must never be
able to push current into an appliance's rail (FR-6).

### 5.4 Power budget

| Condition | 3.3 V draw | 5 V draw (buck, ~90%) |
|---|---|---|
| Idle, WiFi connected | ~40 mA | ~30 mA |
| WiFi RX / normal traffic | ~85 mA | ~65 mA |
| WiFi TX peak (20 dBm) | ~335 mA | ~250 mA |

The Haier's 5 V service rail capability is **not yet measured**. Simulation
(§5.8) establishes the minimum the design needs; measurement (§12) confirms the
appliance provides it. Both gate fabrication.

### 5.5 Programming and recovery

USB-C is the only programming, logging and debug interface
([ADR 0002](adr/0002-c3-and-usb-only-programming.md)). A virgin C3 enumerates on
its ROM USB Serial/JTAG and esptool drives it into download mode unaided, so
first flash needs no buttons.

BOOT (GPIO9) and RESET (EN) tact switches exist for the cases where that fails:
firmware repurposing GPIO18/19, a wedged USB peripheral, a hard boot-loop.

No TC2050 footprint. The ESP32-C3 has no external JTAG pins, so a pogo footprint
would carry the same USB pair as the USB-C connector and add nothing.

### 5.6 Protection

- **330 Ω, 1% series resistors** on TX and RX, selected from the powered-down
  appliance RX bias measurement. They limit fault current if a line meets 5 V
  or GND during install.
- The single four-channel ESD array protects the two JST UART signals and USB
  D+/D−. The interfaces are not used concurrently, but this assignment protects
  either interface from an accidental cable connection without another device.
- Port 5 V current limiting and reverse blocking are provided by TPS2553;
  source isolation is completed by the LM66200 ideal-diode OR.

### 5.7 Indicators and test access

One power LED, high-value resistor. No status LED and no TX/RX activity LEDs —
serial traffic is observable through ESPHome's own logging, which makes
dedicated hardware indicators redundant.

Test pads on 5 V, 3V3, GND, and **both the 3.3 V and 5 V side of each translator
channel**. These are bare copper at zero BOM cost and are what make ADR 0001's
"don't debug translation after assembly" argument actually hold.

### 5.8 Simulation

Simulation is scoped to the **power path only** and gates fabrication.

Nothing else on the board benefits. The C3-MINI-1 has no SPICE model — its
relevant behaviour is a pulsed current source. The translators ship as IBIS, not
SPICE, and answer signal-integrity questions that do not exist at 9600 baud over
a short harness; the translator question that does matter (drive strength into
an unknown appliance's pull-ups) is a DC calculation.

Three decks in `sim/`:

| Deck | Question it answers |
|---|---|
| `rail-sag` | Given a current-limited source, bulk capacitance and a 250 mA WiFi burst, does 3.3 V stay above the C3's brownout threshold? Swept across source current limit. |
| `inrush` | What does the appliance see at plug-in, with the eFuse limit set to a given value? |
| `buck-load-step` | Does the buck recover from a 30 → 250 mA step without undershooting brownout? |

`rail-sag` is the important one. Its output is not "it works" but a **number**:
the minimum source current this design tolerates. That converts the project's
largest unknown from a blocker into a specification to go and measure against,
and quantifies what extra bulk capacitance would buy if the Haier falls short.

**Status (2026-09-12).** `rail-sag` and `inrush` are written and run; results
and the numbers they produced are in [sim/README.md](../sim/README.md). In
short: sag is an average-current problem, so 470 µF is the right bulk value and
adding more would not rescue a weak rail; and the eFuse limit must sit strictly
below the appliance's own limit, which puts the appliance requirement at
**300–370 mA**, not the 250 mA of §5.4.

`buck-load-step` uses the TPS62162 vendor model, because its question is about
the converter control loop and cannot be answered by a behavioural block. The
corrected 2026-09-20 deck ties the fixed-output part's `FB` pin to AGND and
passes the 40 → 335 mA load step with at least 285 mV margin to 3.0 V. Results
are in [sim/README.md](../sim/README.md).

**2026-09-28:** `rail-sag` and `inrush` now model the bulk capacitor with
Nichicon's own model for the PCL1A471MCL1GS, supplied on request, and use the
fitted 400 mA eFuse limit. Every result is unchanged. The model's typical ESR
is 8.6 mΩ against the datasheet's 17 mΩ maximum, which confirms the part.

Simulation lives **outside** the KiCad flow. KiCad 10's built-in ngspice can
simulate a schematic, but the questions here are about a power path that spans
an appliance, a cable and a converter — most of which is not on the board and
has no symbol. The decks are standalone SPICE netlists, which also keeps them
readable and diffable on their own terms.

**Simulator: LTspice.** Homebrew cannot build ngspice on this machine — macOS
12.7.6 is past Homebrew's support window, and `brew install ngspice` fails
trying to compile gcc from source. KiCad bundles `libngspice` as a shared
library with no CLI. LTspice is a native macOS download, needs no toolchain, is
auto-detected by `kicad-happy`'s `spice` skill, and is the format many vendors
publish their models in — which matters given §7.1 requires parts with published
SPICE models.

## 6. Toolchain

**KiCad 10 is the single source of truth**: schematic → netlist → PCB, the
standard flow, with ERC built in. This reverses the original decision to make
atopile the source of truth and reduce KiCad to layout. The reasoning, the
evidence gathered by actually running the tools, and the three
code-to-schematic generators evaluated and rejected are in
[ADR 0005](adr/0005-kicad-native-capture.md).

| Artefact | Owner | Hand-edited? |
|---|---|---|
| `*.kicad_sch` | KiCad 10 | **Yes — this is the source.** Capture lives here |
| `*.kicad_pcb` | KiCad 10 | Yes — netlist updated from the schematic |
| `*.kicad_pro` | KiCad 10 | Yes — carries the DRC rules and net classes from [layout-rules.md](layout-rules.md) |
| netlist | `kicad-cli sch export netlist` | No |
| gerbers, drill | `kicad-cli` | No |
| BOM | `kicad-cli sch export bom` | No |
| `-sch.pdf` | `kicad-cli sch export pdf` | No |
| `sim/*.cir` | hand-written | Yes — standalone, outside the KiCad flow (§5.8) |

Nothing among the design files is generated, so nothing can be silently
regenerated over — which is why there is no "never hand-edit this" rule any
more. The checks are mechanical instead: `kicad-cli sch erc` and
`kicad-cli pcb drc`, both of which run today.

**Review tooling.** `kicad-happy` (v2.2.1, MIT) is installed as a Claude Code
plugin and reviews the `.kicad_sch` and `.kicad_pcb` directly. A hand-drawn
schematic is precisely the artifact it was built to read, and having one is what
makes the first review gate (§12.1) possible at all.

## 7. Components and sourcing

### 7.1 Component quality policy

The design optimises for a *balanced* product, not a minimal BOM. Where a
branded part yields a better result, it is used. Where extra decoupling improves
behaviour, it is added.

Specific consequences on this board:

| Part | Policy |
|---|---|
| Bulk capacitor | Polymer or hybrid aluminium (Panasonic, Nichicon, Würth), not generic electrolytic. The reason is **no dry-out** in a warm appliance, *not* ESR — the load step needs only 185 mA, so even 200 mΩ would cost 37 mV. Do not pay for exotic ESR here |
| MLCCs | Chosen with **DC-bias derating** accounted for. A 10 µF 0603 6.3 V X5R can lose most of its capacitance at 5 V; use larger case sizes and 16–25 V ratings so the nameplate value is close to the real one |
| Inductor | Shielded, branded (Coilcraft, Würth, TDK, Bourns), with genuine saturation margin over the peak — and a published SPICE model (§5.8) |
| Buck, eFuse, ideal diodes | Branded silicon with vendor SPICE models and real datasheets |
| TVS array | Purpose-made ESD protection array (Nexperia, Semtech, onsemi), not a generic diode |
| Connectors | Genuine JST XA and a branded USB-C receptacle with through-hole retention |
| Decoupling | Added generously. Both VCCA and VCCB on every translator, multiple values at the module, bulk plus ceramics on every rail |

### 7.2 Sourcing

**Every component is pinned by MPN on its schematic symbol, passives included.**
There is no automatic part picker in this flow — removing atopile removed the
one that had to be suppressed anyway (ADR 0005). A substitution reaching the
board without a decision having been made is the failure mode being designed
against, and the defence is now review rather than configuration.

The exported BOM carries MPN plus LCSC and Digi-Key/Mouser numbers, and PCBWay
sources from whichever it can. Substitutions are proposed back, never applied
silently.

**Additional selection criterion:** because simulation gates fabrication (§5.8),
the **buck** must be a part whose vendor publishes a usable SPICE model. TI and
ADI generally do; several cheaper LCSC-catalogue alternatives do not — including
the AOZ1280CI on `daikin-esp`'s `esp-daikin-r1p1`, which is why that part is not
simply carried over. This applies before the buck is committed to the design.

The criterion does **not** extend to the eFuse. Its deck's question is answered
by the current limit alone, which a behavioural block models exactly; requiring
a vendor model there would narrow the field for nothing. Reasoning and
consequences are in the 2026-09-12 amendment to
[ADR 0004](adr/0004-current-limited-inrush.md) — in exchange, the eFuse's
current-limit *accuracy* becomes a first-order selection criterion, because it
is what sets the appliance requirement.

### 7.4 Parts register

Filled in as parts are pinned. Every entry is a decision with a reason, not a
search result. Until the schematic exists this is the record; afterwards the
schematic symbols carry the MPNs and this table points at the reasoning.

| Function | MPN | Why this one |
|---|---|---|
| 3.3 V buck | **TPS62162DSGT** (WSON-8, 2×2 mm; `T` = 250-piece reel) | Fixed 3.3 V, so no feedback divider. `FB` is tied to AGND and `VOS` senses at the output capacitor, per the datasheet; the latter remains a control-loop-sensitive layout net. 1 A against a 335 mA peak. The only candidate with both a fixed output *and* an unencrypted SPICE model — TPS6282533 has no published model, TPS62901's is 74% Cadence-encrypted. Costs ~2 efficiency points against the TPS6282x, worth ~5 mA of appliance current, which is noise against a 300–370 mA requirement ([ADR 0003](adr/0003-buck-not-ldo.md), §5.8) |
| Buck inductor | **XGL4020-222MEC** (Coilcraft) | 2.2 µH, 19.5 mΩ DCR against the XFL3012's 97 mΩ — buys back ~0.8 of the ~2 points conceded above. Isat 2.7 A sits clear of the IC's ~1.6–2 A current limit, so the IC protects before the inductor saturates. Coilcraft publishes a `_sat` LTspice model, verified against the datasheet before use. 2.0 mm tall, confirmed to clear the enclosure |
| Port connector | **B05B-XASK-1-A(LF)(SN)** (JST XA, 5-pin, vertical, with boss) | Matches the appliance's XARR-05V panel housing, so the harness is straight-through (§5.2). Vertical entry confirmed against the enclosure. `-A` for the boss: this is the board's only permanent mechanical interface and takes every insertion force in a unit that vibrates, so the boss carries that into the board rather than the solder joints. Tin, not `-GU` gold — plating should match across a mating pair, and standard XA crimps are tin. **Through-hole**, so it needs a selective- or hand-solder step on an otherwise all-SMD board |

| Level translator | **TXU0204RUTR** (`RUT` UQFN-12, 2.0 × 1.7 mm) | 4-bit fixed-direction, two channels each way — TI names UART as the application. Direction fixed in *silicon*, so there is no DIR pin to mis-strap; Schmitt-trigger inputs for a metre of harness; integrated pull-downs, which retire ADR 0001's own warning about floating unused inputs. Push-pull ±12 mA at 4.5 V against the ~4 kΩ of the auto-direction parts ADR 0001 rejected. Two channels unused. See the 2026-09-13 amendment to [ADR 0001](adr/0001-fixed-direction-level-translation.md) |

| eFuse | **TPS2553DBVR** (SOT-23-6) — **not the `-1`** | ADR 0004's part. 75 mA–1.7 A adjustable limit, 2.5–6.5 V, 85 mΩ, active-high enable, **reverse blocking**, thermal shutdown, constant-current limiting rather than latch-off (the `-1` suffix latches; we do not want that). Unencrypted PSpice model exists, though ADR 0004's amendment means one is not required here. `R<sub>ILIM</sub>` is selected from the inferred rail envelope under ADR 0007, then checked at bring-up. |
| Ideal-diode OR | **LM66200DRLR** (SOT-5X3-8, its only package) | 1.6–5.5 V, 40 mΩ, 2.5 A, low I<sub>Q</sub>, **two ideal diodes in one package** — both OR branches in a single part instead of two LM66100s. Unencrypted PSpice model |

| ESD array | **TPD4E05U06QDQARQ1** (TI, AEC-Q101) | Quad, 0.5 pF, V<sub>RWM</sub> 5.5 V, min breakdown 6.5 V, ±12 kV, 2.5 A / 40 W surge. Channels protect JST TX/RX and USB D+/D−; the ports are mutually exclusive in normal use, but both remain protected against an accidental cable connection. The `-Q1` is taken for its temperature grade, not automotive compliance — this board lives in a warm appliance with no enclosure. **Caveat:** 5.5 V standoff against 5 V logic is 0.5 V of margin, so the Haier's open-circuit rail voltage must be confirmed (already on the bench list) |
| USB-C receptacle | **USB4085-GF-A** (GCT) | USB 2.0, 16 contacts, through-hole, horizontal top-mount, four PCB retention/grounding posts, 10 000 mating cycles, 3.46 mm profile. Through-hole retention is what §7.1 asked for, and it shares the selective-solder step the JST already needs. **KiCad 10 ships both a reviewed footprint and a STEP model** for it, which is not true of any vertical receptacle. Vertical was considered: it would free ~9 mm of long edge we do not need, in exchange for the cable levering perpendicular to the board and hand-sourced library assets |

| Bulk capacitor | **PCL1A471MCL1GS** (Nichicon) | 470 µF, 10 V ±20%, conductive polymer aluminium **solid** — no liquid electrolyte, so nothing to dry out, which is the entire reason for this class of part here. 8 × 10 mm SMD, ESR 17 mΩ, ripple 3.8 A, −55 to +105 °C. Double the voltage margin on a 5 V rail; the ±20% worst case of 376 µF is still comfortable, since `rail-sag` showed even 220 µF costs only 55 mA at light duty. ESR and ripple ratings are enormously in excess of what is asked of them, and deliberately not paid for |

| Module | **ESP32-C3-MINI-1-H4X** (Espressif) | 4 MB flash — ample for an ESPHome image plus OTA partitions, with no filesystem to speak of. **H = 105 °C** ambient rather than the N variant's 85 °C, for a bare board in an HVAC unit. **X = chip revision v1.1, and it is not optional: every non-X variant is NRND.** Plain `-1`, *not* `-1U` — the U denotes a U.FL connector and no antenna at all, whereas `-1` carries the PCB trace antenna this design settled on ([haier-oem-board.md](haier-oem-board.md)). Keeping the PCB antenna is what makes the antenna keepout layout priority #1; `-1U` has no keepout, but needs an external antenna and a pigtail inside the chassis |

**Passives pinned 2026-09-20**, once the schematic fixed how many of each there
are. Two families, chosen for consistency rather than per-line optimisation:

| Function | MPN | Why this one |
|---|---|---|
| All five resistor values — 330 Ω ×2, 5.1 kΩ ×3, 10 kΩ ×2, 66.5 kΩ, 100 kΩ ×2 | **KOA Speer RK73H 1J** series, 0603, ±1% | One series across every value: ±100 ppm/°C, −55…+155 °C, AEC-Q200. The 66.5 kΩ `RILIM` **has** to be 1% — the TPS2553 datasheet says so, it is not a preference — and running the same grade everywhere costs cents and removes a class of mistake. Size code `1J` = 0603 and tolerance code `F` = ±1% are confirmed from the ordering table in the datasheet |
| 100 nF ×4, 1 µF ×3, 10 µF ×2, 22 µF | **Samsung CL** series, **X7R only, ≥25 V** | X7R throughout, never X5R: TPS62162's LC stability table assumes variation stays within ±20% *including DC bias*, and 25 V parts on a 5 V rail keep the derating small enough to stay there. The 22 µF output value and its dielectric are the datasheet's own recommendation |
| Power LED | **LTST-C191KGKT** (Lite-On, 574 nm) | Vf 1.9–2.4 V puts ~0.6 mA through the 5.1 kΩ — dim on purpose (§5.7). Chosen over the 5× brighter emerald-green `LTST-C191TGKT` for temperature grade: −55…+85 °C against −20…+80 °C, consistent with the H-grade module and the `-Q1` ESD array |
| BOOT/RESET switches | **C&K KMR211NGLFS** | −40…+85 °C, 200 000 operations, 1.2 N. `NG` is the ordering key's **no ground pin** option, which is what picks the four-pad land pattern over the five-pad one. C&K's recommended layout — 0.9 × 1.0 mm pads at ±2.05, ±0.8 mm — matches KiCad's footprint exactly |

**The switch datasheet changed a resistor.** C&K specify a **minimum contact
current of 1 mA** for the standard silver contacts; the ULC option exists
precisely because 1 mA is a lot for a logic-level button, and it is not stocked
anywhere this project can check. With a 10 kΩ pull-up, SW1 would have switched
0.33 mA — a third of the vendor's minimum, in the dry-circuit region where
contact films do not get broken down.

- **R9 (BOOT) is therefore 2.2 kΩ, not 10 kΩ.** That puts 1.5 mA through SW1,
  50% above the minimum. GPIO9 is a strapping pin read once at reset, so the
  only cost is 1.5 mA while the button is physically held.
- **R10 (EN) stays 10 kΩ.** SW2 discharges C11's 1 µF through its contacts on
  every press, which is a far larger wetting pulse than any steady current would
  be, so the low steady current does not matter there. Shortening the EN time
  constant would also have been the wrong move while the manual-reset-on-first-
  power-up anomaly (§13) is unexplained. *The wetting-pulse argument is
  engineering judgement, not a vendor statement.*

The **two 5.1 kΩ CC pulldowns** the USB-C sink needs are R3 and R4, sharing a
line with the LED series resistor R8.

**Endurance resolved (2026-09-20).** The Nichicon datasheet, now in
[lib/datasheets](../lib/datasheets/), states **20 000 hours at 105 °C**, twice on
the same page. The 2 000 h figure some sources carry is wrong. That datasheet also
confirms this entry's 17 mΩ ESR and 3.8 A ripple, gives the case as 8 × 10 mm, and
adds leakage of 940 µA at rated voltage.

**Stock confirmed for every line above (2026-09-20).** All ten are obtainable,
but across three distributors — Digi-Key, LCSC and Mouser — and three of them
are single-source. The eFuse problem is resolved; see §13. Per-line stock,
distributor part numbers and cost are in [bom/](../bom/); the numbers go stale,
so re-check before ordering.

**`lib/` is started (2026-09-19).** Symbols and footprints exist for every part
above except three, 3D models for six, and datasheets for eight. It validates
under `kicad-cli` and references nothing outside the repo.
[lib/README.md](../lib/README.md) carries the per-asset provenance, the gap
list, and the pin tables extracted from the datasheets for the symbols still to
be authored. Gaps needing an external source: the `XGL4020` footprint and 3D
model, the `LM66200` DRL-8 footprint and 3D model, 3D models for the JST XA and
TI's DSG0008A, and the JST and Nichicon datasheets.

### 7.3 Project library

Every symbol, footprint and 3D model the design uses lives in `lib/` in this
repo, referenced with `${KIPRJMOD}`-relative paths in `fp-lib-table` and
`sym-lib-table`.

The design is **not** limited to KiCad's stock libraries — parts are chosen for
the design and their library assets sourced from SnapEDA or the vendor as
needed. Datasheets for every non-passive are kept alongside.

Nothing in the design may reference a library outside this directory. A board
that only opens correctly on the author's machine is not reproducible, which
matters most for an open-hardware release.

## 8. Mechanical and fabrication

| Parameter | Value |
|---|---|
| Stackup | 4-layer: L1 signal+parts / L2 GND / L3 rails+escapes / L4 GND, on PCBWay's standard 1.6 mm build with 1 oz inner copper |
| Outline | **22 × 54 mm** — drop-in for the OEM Haier board. JST on one short edge, USB-C on an adjacent long edge, antenna at the far short edge |
| Fab class | PCBWay 5/5 mil, 0.2 mm drill (0.25 mm until 2026-09-24 — see layout-rules.md) |
| Impedance | Not controlled; USB pair estimated at ~101 Ω on the real stackup |
| Assembly | Single-sided, all parts on top. All SMD except the JST XA port connector and the USB-C receptacle, which are through-hole and need a selective- or hand-solder step |
| Quantity | 5 (first run) |
| Enclosure | None — bare board |
| Mounting | None — no mounting holes; the board sits in the OEM board's slot (measured 2026-09-20) |
| Antenna | C3-MINI-1 placed at a board edge, keepout on all layers, buck switching node kept clear |

4 layers because the switcher and a PCB antenna share a small board; a solid
ground plane turns EMI and antenna reference from a layout puzzle into a
non-issue. With no components on the bottom, L4 is a second ground plane for
free — a return path and a shield under the buck.

Binding layout rules, DRC values, DFM constraints and a pre-release checklist
are in **[docs/layout-rules.md](layout-rules.md)**. The short version: three
circuits deserve real rules — the buck's input hot loop, the antenna keepout,
and the USB pair — and the ground plane is never split.

The C3's USB is Full Speed (12 Mbps), so controlled impedance is not ordered;
the pair is still routed as a proper, tightly coupled pair. Its 0.20 / 0.20 mm
geometry comes out at ~101 Ω on PCBWay's published stackup, an estimate that
is inside USB's 90 Ω ±15 % (see layout-rules.md, review gate 2).

Bare board is a deliberate choice. It means exposed electronics near HVAC
condensate and mains wiring — acceptable for a personal install, not for
anything distributed.

## 9. Firmware

ESPHome, using the **`esphome-gea` external component in GEA3 mode at 230400
8N1** on the port's UART, with logging over USB CDC. OTA is the normal update
path after first flash. The YAML lives in an `esphome/` directory.

The reference appliance speaks GE Appliances GEA3, **not** Haier hOn, and
ESPHome's built-in `haier` component does not apply to it. Decoded 2026-09-18
and confirmed two-way on the appliance 2026-09-19; see
[ADR 0006](adr/0006-gea3-not-hon.md) and [gea3.md](gea3.md) for the evidence
and the ERD map. SerialTap takes bus address `0xBF`; the appliance is `0xC0`.

`esphome-gea` provides sensor, binary_sensor, switch, select, number and
text_sensor entities over ERDs. It has no climate entity, so that is the one
piece of firmware still to write. Control is writing ERDs `0x7A0F` power,
`0x7A01` mode, `0x7003` setpoint, `0x7A00` fan and `0x7B07`/`0x7B08` swing.

Because GEA3 also has a plain C implementation in GE's `tiny-gea-api`, nothing
in this design depends on ESPHome or on Home Assistant. Neither is load-bearing
for the hardware.

## 10. Deliverables

```
/
├── CONTEXT.md                  domain language
├── LICENSE                     CERN-OHL-P v2, verbatim
├── LICENSE-MIT                 firmware and docs
├── NOTICE                      which licence covers what, and third-party terms
├── docs/
│   ├── SPDD.md                 this document
│   ├── adr/                    decision records
│   ├── layout-rules.md         binding layout rules, DRC, DFM, checklist
│   └── harness/                cable pinouts per appliance
├── lib/                        project library: symbols, footprints, 3D, datasheets
├── sim/                        standalone LTspice decks (§5.8)
├── pcb/
│   ├── serialtap.kicad_sch     source of truth
│   ├── serialtap.kicad_pcb
│   ├── serialtap.kicad_pro
│   └── fab/                    regenerated output: gerbers, drill, BOM, CPL,
│                               assembly and schematic PDFs; gitignored until release
├── bom/                        sourcing BOM and cost notes
├── esphome/                    ESPHome package, incl. loopback self-test build
└── test/                       loopback plug build notes, acceptance checklist
```

Board name is `serialtap`, and that is the whole file name — **no revision is
carried in file or folder names**. Freezing a design is what version control is
for: the commit a fab order is built from is tagged, and a revision suffix
would only duplicate the tag, badly (renamed from `serialtap-r1p0`,
2026-09-24).

**Flat.** Everything for the board lives directly in `pcb/`. One board and a
handful of files do not need a directory tree.

## 11. Requirements traceability

| Req | Satisfied by |
|---|---|
| FR-1 | §5.1 fixed-direction translators |
| FR-2 | §5.2 JST XA carrying 5 V + data, §5.3 power path, §5.8 simulated against a weak source |
| FR-3 | §5.1 push-pull translation; §5.6 series R sized for it |
| FR-4 | §5.5 C3 ROM USB Serial/JTAG + esptool |
| FR-5 | §5.5 BOOT and RESET switches |
| FR-6 | §5.3 ideal-diode OR on both sources |
| FR-7 | §5.6 series R, ESD array, TPS2553 current limit and reverse blocking |
| FR-8 | §9 ESPHome OTA |

## 12. Validation

### 12.1 Design validation

Gating tasks, in order. The design is not validated until all pass.

Automated review by `kicad-happy` runs at three points alongside these: after
the schematic is captured (feedback network, decoupling, ESD coverage by
connector, fuse sizing, temperature grade, EOL parts), after layout (thermal
vias, plane voids, trace width, impedance, DFM score), and before upload to
PCBWay. It is a
review aid — it does not replace `kicad-cli` ERC/DRC, the layout-rules
checklist, or the physical measurements below.

1. **Simulate the power path** (§5.8). `rail-sag` yields the minimum source
   current the design tolerates; `inrush` sets the eFuse limit resistor;
   `buck-load-step` confirms no brownout on a 30 → 250 mA step.
   *Complete. `buck-load-step` was re-run 2026-09-20 with fixed-output `FB`
   tied to AGND; it passes with ≥285 mV margin to 3.0 V.*
2. **Measure the Haier's 5 V rail** — open-circuit voltage, current limit, and
   sag under a 250 mA pulsed load — and confirm it exceeds the number from
   step 1. This is the single largest unknown in the design.
   The number to beat is now **≥ 370 mA** for full margin; 250–300 mA means
   OTA and association on appliance power are at risk; below 250 mA the design
   needs rethinking, and not with capacitors. Also record what the rail *does*
   in current limit — droop, foldback, or reset — which the decks assume is a
   droop. Detail in [sim/README.md](../sim/README.md).
3. **Confirm the AS50QDFHRA service connector pinout** by probing the unit. The
   board pinout is fixed and conventional, so this determines the *cable*, not a
   respin.
4. Bench bring-up: rails correct, current draw within §5.4, no brownout at
   plug-in.
5. Scope both sides of both translator channels at **230400 8N1** against a
   USB-serial adapter. Confirm clean push-pull levels, not RC-shaped edges.
6. ESPHome flashes over USB-C on a virgin board with no button presses.
7. Manual recovery works: hold BOOT, tap RESET, device enters download mode.
8. OTA update succeeds while powered **only** from the appliance rail — the
   worst-case current condition.
9. End to end: the board controls the Haier from Home Assistant.

### 12.2 Per-board acceptance test

Applied to each of the five assembled boards before it goes into service.

**Loopback plug.** A JST XA shell with TX bridged to RX. A test ESPHome build
transmits a pattern on the port and verifies it returns, which exercises the
whole chain in one step: 3.3 V → up-translator → connector → down-translator →
3.3 V, plus both series resistors and the solder joints on all of it.

It needs no scope and no appliance. VCCB derives from the OR-ed 5 V rail, so
USB-C alone powers the 5 V side — the test runs on a bench with one cable.

| Step | Pass condition |
|---|---|
| 1 | Board enumerates over USB-C and flashes with no button presses |
| 2 | 5 V and 3V3 test pads within tolerance; idle current within §5.4 |
| 3 | Loopback self-test returns the pattern intact |
| 4 | Joins WiFi and accepts an OTA update |

What the loopback does **not** prove: real push-pull drive strength into a
loaded 5 V line. The first board additionally gets a scope on the translator
test pads to confirm square edges rather than RC-shaped ones. Boards 2-5 inherit
that result.

## 13. Risks and open questions

| Risk | Impact | Mitigation |
|---|---|---|
| Haier 5 V rail too weak for WiFi TX bursts | Board browns out on association; may reset the appliance | Buck over LDO, current-limited turn-on, ≥470 µF bulk. Simulated (§5.8): the rail must supply **300–370 mA**, and more bulk would not buy the shortfall back. **Risk substantially reduced:** the OEM board this replaces ran a Realtek RTL8720CM from the same rail, rated 450 mA at 3.3 V — more than our C3's 335 mA — through its own buck ([haier-oem-board.md](haier-oem-board.md)). Still **measure before committing to fab** (§12.1-2) |
| Haier connector pinout assumed, not confirmed | Cable is wrong; nothing communicates | Fixed board pinout makes this a cable fix, not a respin (§12.3) |
| Buck switching noise coupling into the antenna | Degraded WiFi range inside an appliance | Zoned floorplan (buck at the connector end, antenna at the far edge), minimised switch node, two ground planes — see layout-rules.md |
| Silent part substitution at assembly | A cheaper equivalent lands on the board and changes behaviour | Every part pinned by MPN (§7.2); substitutions proposed back, never applied silently |
| Bare board in an HVAC unit | Condensate, mains proximity, handling damage | Accepted for personal use; documented as unsuitable for distribution |
| No SPICE model for a chosen buck or eFuse | Power path cannot be simulated, removing the fab gate | Vendor SPICE model is a part-selection criterion (§7) |
| Direction frozen in copper | A future half-duplex target needs a new board | Accepted — explicitly a different product (ADR 0001) |
| Single UART, no spare | A second serial device needs a different module | Accepted (ADR 0002) |

**Open questions**

- ~~Actual current capability of the Haier 5 V service rail~~ **No longer a
  fabrication gate ([ADR 0007](adr/0007-rail-limit-inferred-not-measured.md)).**
  `RILIM` is set from inference instead: above SerialTap's worst-case draw and
  below the OEM-implied floor of the rail. The rail has been observed carrying a
  TinyS3 with Wi-Fi live (2026-09-19). Still unmeasured, and the cost of that is
  recorded in ADR 0007
- ~~Buck and eFuse MPNs~~ **Both pinned (§7.4):** TPS62162 and TPS2553.
  The corrected buck deck passes; `RILIM` is set per ADR 0007 and checked at
  bring-up.
- ~~**`TPS2553DBVR` availability.**~~ **Resolved 2026-09-20 by the first of the
  three escape routes: another distributor.** The plain non-latching part is
  stocked at **LCSC (C55266, 44,248)** and **Mouser (882)**. Digi-Key remains out
  until 2026-10-26 — the 2026-09-19 finding was correct about Digi-Key, and only
  the conclusion drawn from it was wrong. `TPS2552DBVR` and the
  `-1`-plus-auto-retry circuit of the datasheet's §10.2.2 are therefore both
  unnecessary; the reasoning for rejecting the `-1` (it latches off on
  overcurrent, and with 470 µF of bulk the plug-in charge time is the same order
  as its 8 ms fault deglitch, so it could latch at every plug-in inside an
  appliance) stands unchanged. No design or library change.
  **One check owed at goods-in:** LCSC's auto-generated listing text mentions
  latch protection, which is boilerplate for the whole TPS2553 family and says
  nothing about the suffix — verify the package marking on receipt.
- **`PCL1A471MCL1GS` depth.** Not a blocker, but the thinnest line on the BOM:
  **69 pieces at Mouser, and nowhere else.** Digi-Key is non-stock at 24-week
  lead and a 500-piece minimum; LCSC does not list it, and the sister
  `PCR1E471MCL1GS` shows 22-week lead and no stock at Arrow, so this is the
  series rather than the one part number. Buy spares in the same order. If that
  stock goes first, the fallback is a different 470 µF / 10 V polymer — a
  substitution, proposed back and never applied silently (CLAUDE.md, §13 risk
  table).
- **Which ERD carries which control** on the reference appliance. Firmware only,
  no hardware impact. Ten of the 64 ERDs are unnamed in GE's public definition
  set, and the appliance reads ERD `0x6003` from the module every 30 s for
  reasons unknown ([gea3.md](gea3.md))
- **Why the board needed a manual reset** on its first power-up from the
  appliance rail (2026-09-19). The one open item that could still change the
  design, because it concerns enable and reset timing on a rising rail
- ~~AS50QDFHRA service connector **pin order**~~ **Settled 2026-09-20**: the
  connector had been read from the wrong end. Corrected order is 5 V, TX, RX,
  spare, GND, with direction fixed by the working TinyS3 link (§5.2). What
  **pin 4** carries is still unknown, and still blocks nothing but the harness.
  Connector and mating part known since 2026-09-12: 5-pin JST XA, 2.5 mm pitch,
  XARR-05V panel housing
- Whether a board-mounted JST XA or a wire-to-board pigtail suits the install
- ~~PCB antenna or external?~~ **Settled: PCB antenna (ESP32-C3-MINI-1).** The
  OEM board provides a U.FL footprint but it was never populated — that unit ran
  on its own antenna inside this chassis for its service life. The reference
  install also has an access point ~3 m away with line of sight. The **-1U**
  variant is the fallback if bring-up shows poor RF
  ([haier-oem-board.md](haier-oem-board.md))

## 14. Decision log

| ADR | Decision |
|---|---|
| [0001](adr/0001-fixed-direction-level-translation.md) | Fixed-direction level translation, not auto-direction |
| [0002](adr/0002-c3-and-usb-only-programming.md) | ESP32-C3-MINI-1, programmed over USB only, no TC2050 |
| [0003](adr/0003-buck-not-ldo.md) | Synchronous buck, not an LDO, for the 3.3 V rail |
| [0004](adr/0004-current-limited-inrush.md) | Current-limited inrush protection, not slew-rate-limited |
| [0005](adr/0005-kicad-native-capture.md) | KiCad-native capture; atopile removed, and the code-to-schematic alternatives rejected on evidence |
| [0006](adr/0006-gea3-not-hon.md) | The appliance protocol is GE Appliances GEA3, not Haier hOn |
| [0007](adr/0007-rail-limit-inferred-not-measured.md) | The rail's current limit is inferred, not measured; the load test stops gating fabrication |

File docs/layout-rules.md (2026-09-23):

# Layout rules — SerialTap

Binding rules for board layout in KiCad 10. Referenced by
[SPDD §8](SPDD.md). Numbers assume PCBWay's **5/5 mil, 0.2 mm drill** class (0.25 mm until
2026-09-24 — see *Design rules*).

## Priority order

When rules conflict, this is the order they win in:

1. **Antenna keepout.** Non-negotiable, set by Espressif.
2. **Buck input hot loop.** The fastest di/dt on the board.
3. **ESD path at the connector.**
4. **USB pair integrity.**
5. Everything else.

Place in that order too. The module and the buck are placed first; the rest
fills in around them.

## Stackup

| Layer | Assignment |
|---|---|
| L1 | Signal + all components (single-sided assembly) |
| L2 | **Solid ground.** Unbroken. Reference for every L1 signal and the antenna. |
| L3 | 5 V and 3V3 pours, plus escape routing |
| L4 | **Ground.** Second return path and shield under the buck. No components. |

**Encoded in `pcb/serialtap.kicad_pcb`: PCBWay's published standard
4-layer 1.6 mm build** ([multi-layer laminated structure](https://www.pcbway.com/multi-layer-laminated-structure.html),
70 % residual-copper variant, which suits a near-solid L2): 35 µm outer
(0.5 oz plated to 1 oz), **7628 RC46 % prepreg 0.1855 mm, Dk 4.74**, 35 µm
(1 oz) inner, **1.03 mm core, Dk 4.6**, symmetric; 1.61 mm finished, ±10 %.
Loss tangent is unpublished; 0.02 is assumed. **Order with 1 oz inner
copper** — the stackup assumes it. (Until 2026-09-24 the board carried a
provisional 0.2104 mm / 1.065 mm / 17.5 µm-inner stackup.)

## Floorplan

Board outline **22 × 54 mm**, chosen to drop into the OEM Haier board's place.
Zones run along the 54 mm axis:

```
  |<--------------------------- 54 mm --------------------------->|
  +----------------------------------------------------------------+
  | ANTENNA  |  C3-MINI-1  | translators  |   power    |    JST     |  22
  | keepout  |   module     | + TVS + Rs   | OR/eFuse   |  5-pin XA  |  mm
  | no copper|              |              | bulk, buck |            |
  +-------------------------------------------[ USB-C ]-------------+
                                               long edge
```

- Antenna at one short edge, 0.25 mm inside the OEM rectangle over a
  copper-free keepout on all four layers. (The first plan relieved the outline
  so the antenna overhung; keeping the OEM outline, 2026-09-22, ruled it out.)
- **JST on the far short edge; USB-C on a long edge beside it.** They do not
  both fit across 22 mm: a 5-position XA header is ~14.6 mm and a USB-C
  receptacle ~8.9 mm, which needs ~26 mm with edge clearance between them.
  The JST keeps the short edge because it is the permanent harness and wants a
  clean cable exit; USB-C is bench-only and unused after first flash (ADR 0002).
  Both still land at the same end, so the two 5 V sources still meet at the
  ideal-diode OR without crossing the board.
- Buck biased toward the connector end — maximum distance from the antenna.
- TVS and series resistors **at the JST**, not at the translators. The
  unprotected side of the ESD devices must be as short as possible; the 3.3 V
  side takes the long run to the module, where it is harmless.

## Area budget — measured from the footprints, 2026-09-20

The board is **1188 mm²** (22 × 54). The courtyards of all 33 components total
**774 mm², or 65%** of that. Tight but routable on four layers; the usual pain
threshold is 70–80%.

It is less crowded than "33 components" sounds, because four parts are 71% of
the area and the other 29 share what is left:

| Part | Courtyard | mm² |
|---|---|---:|
| U6 ESP32-C3-MINI-1 | 13.6 × 17.0 | 231 |
| J1 JST XA 5-pin | 16.0 × 7.4 | 118 |
| J2 USB-C | 10.6 × 10.2 | 107 |
| C4 bulk 470 µF | 10.5 × 8.8 | 92 |
| **those four** | | **548** |
| the other 29 (5 ICs, inductor, 2 switches, 20 passives, LED) | | **226** |

So placement is really "fit four large objects to the floorplan, then fill".
The module's 231 mm² already includes its antenna end, which is where the
keepout lives — the keepout does not cost additional area, it constrains what
may sit *near* it.

Every footprint has a courtyard (the `LM66200` one was missing at this
budget and has since been fixed), and DRC treats a missing courtyard as an
error, not *ignore* as it first did (2026-09-23).

## Per-circuit rules

### Buck converter

The critical net is not the switch node — it is the **input loop**:
`input ceramic → high-side FET → low-side FET → ground → back to ceramic`.

- Input ceramic capacitor on L1, within 1–2 mm of VIN/PGND. **No vias inside
  this loop.** Via inductance is comparable to the loop being minimised.
- The 470 µF bulk sits *behind* the ceramic. Bulk handles millisecond WiFi
  bursts; the ceramic handles nanosecond switching edges. Do not swap them.
- **Switch node: minimum copper area** consistent with current. This is the one
  net that is deliberately not poured — it is the dV/dt aggressor radiating at
  the antenna.
- Inductor immediately at the SW pin. Short, direct.
- Feedback: 0.127–0.2 mm, sensed at the **output** capacitor, routed away from
  SW and never beneath the inductor. Ground-guard if space allows.
- Thermal pad: via array, 0.2 mm drill, tented with mask on L4. Windowpane the
  paste stencil to ~60–70 % coverage to limit wicking and voiding.
- Stitch L2–L4 with vias around the buck.

### Antenna

- **No copper on any layer** — L1, L2, L3, L4 — in the C3-MINI-1's antenna
  keepout. This includes ground pours. Follow Espressif's module datasheet
  keepout dimensions exactly.
- Module at the board edge, antenna end 0.25 mm inside the outline over the
  all-layer keepout (see *Floorplan*).
- Nothing routed on L3 beneath the antenna either.
- Ring the keepout boundary with ground stitching vias.
- Installation note for the harness docs: keep ≥15 mm clear of metal.

### USB

The C3's USB Serial/JTAG is **USB 1.1 Full Speed (12 Mbps)**. Transmission-line
effects are negligible over ~20 mm, which is why controlled impedance is not
ordered. Route it properly anyway — it costs nothing:

- Same layer (L1), tightly coupled, **no vias, no stubs**.
- Continuous L2 ground reference along the entire run. Never cross a plane gap.
- Length matched within 5 mm.
- Target ~90 Ω differential geometry computed from PCBWay's actual stackup.
  Starting point for a thin L1–L2 prepreg: ~0.20 mm width, ~0.13 mm gap —
  **confirm with KiCad's impedance calculator against the real stackup.**
- Keep ≥0.6 mm from other signals.

### Port protection and translation

Order along the path, nearest connector first:

```
JST pin --> TVS array --> 330 Ω series R --> translator B-side
```

- TVS ground via directly into L2, short and wide. The ESD return path matters
  more than the clamp.
- The TPD4E05U06's other two channels protect USB D+/D− at USB-C. Both ports
  are normally mutually exclusive, but both connector-facing data paths are
  protected against accidental connection.
- 100 nF on **both** VCCA and VCCB of each translator, within 2 mm.
- Tie off unused translator inputs. Never leave them floating.

### Module

- 10 µF + 100 nF at the C3-MINI-1's 3V3 pin.
- Ground stitching under the module's thermal pad into L2.

## Global rules

- **Never split the ground plane.** One solid L2. The instinct to isolate
  "noisy" switcher ground from "quiet" RF ground with a split or star point
  makes things worse — it forces return currents to detour around the gap and
  become loop antennas. Return current is controlled by *placement and zoning*,
  not by copper splits.
- Perimeter ground stitching every ~5 mm.
- No unstitched copper islands.

## Design rules (PCBWay 5/5 mil, 0.2 mm drill)

These are encoded in `pcb/serialtap.kicad_pro` and enforced
by `kicad-cli pcb drc` — verified 2026-09-12 by feeding DRC a deliberately
undersized track and confirming it was rejected against the 0.127 mm minimum.
Net classes `Default` (0.20 mm), `Power` (0.50 mm) and `USB` (0.20 mm / 0.13 mm
gap) are defined there too.

| Rule | Value |
|---|---|
| Min trace width | 0.127 mm |
| Min clearance | 0.127 mm |
| Min drill | 0.2 mm |
| Default via | 0.2 mm drill / 0.50 mm pad |
| Min annular ring | 0.15 mm |
| Copper to board edge | 0.3 mm (0.5 mm preferred for planes) |
| Silkscreen to pad | 0.15 mm; no silk over pads |
| Silkscreen text | **0.8 mm high, 0.15 mm stroke minimum** |
| Solder mask dam | 0.1 mm min |

**Drill moved from 0.25 to 0.2 mm, 2026-09-24.** PCBWay's via minimum
annular ring is 0.15 mm; the old 0.25 / 0.5 mm vias gave 0.125 mm, and DRC
missed it because its own rule was 0.125 mm. Drilling 0.2 mm on the same
pads moves no copper (0.55 mm pads would not fit beside U5). PCBWay charges
extra only below 0.2 mm; 1.6 ÷ 0.2 = 8:1 is their standard aspect-ratio
limit.

**Silkscreen values checked against PCBWay, 2026-09-22.** PCBWay's
capabilities page gives a minimum legend height of 0.8 mm and a minimum
character width (stroke) of 0.15 mm; their engineering FAQ asks for 0.2 mm
silk-to-pad and accepts 0.1 mm where space is tight, and says silk left on a
pad is clipped off at fabrication. The board's DRC stroke minimum was 0.12 mm —
**looser than the fab**, so it was raised to 0.15 mm. Height already matched.
There is no slack to gain by matching PCBWay: their numbers are the floor.

Default widths for non-critical nets:

| Net class | Width |
|---|---|
| Signal | 0.20 mm |
| 3V3 | 0.50 mm or pour |
| 5 V | 0.50 mm or pour |
| GND | plane |

0.5 mm on 1 oz outer copper carries ~1 A at a 10 °C rise — comfortably above the
eFuse limit, so current capacity is never the binding constraint here.

## DFM — single-sided assembly

- All components on L1. L4 carries no parts.
- **3 global fiducials** on L1: 1 mm copper dot, 2 mm mask opening, placed
  asymmetrically. No local fiducials needed — nothing is fine-pitch BGA.
- Passives **0603 by default**; 0402 permitted only where loop area demands it
  (buck input ceramics, translator decoupling).
- Pin-1 and polarity markers on silkscreen, still visible after assembly.
- Designators readable and unambiguous; none hidden under parts.
- Keep components ≥3 mm from the board edge where possible. This board cannot —
  the OEM outline is full — so the panel is tab-routed with tabs placed away
  from the parts at the edge (*Review gate 3*).
- ~~Mounting holes with keepout~~ **N/A — there are none** (measured
  2026-09-20). Retention is **not an open question** (decided 2026-09-22): the
  board keeps the OEM board's 22 × 54 mm outline and sits in the same slot.
- Test points: 1.5 mm exposed copper pads, labelled on silkscreen, reachable with a
  probe without removing the board.

## Recorded exceptions — as routed, 2026-09-22

Where the routed board departs from a rule above, the departure is recorded
here, with the reason, rather than left for a reviewer to rediscover.

1. **The ESD array is not at the JST.** U5 (TPD4E05U06) sits 12.2 mm from
   J1 and 5.5 mm from J2, footprint centre to centre (measured from the board
   file 2026-09-22; the `a80c933` note's 9 mm / 3 mm is the gap between
   parts). One four-channel array serves both connectors, so it cannot sit at
   both. The order *connector → TVS → 330 Ω → translator* still holds on the
   UART lines. **Accepted 2026-09-22.**
2. **The UART from J1 runs on L3, with L1 hops.** Permitted by the stackup
   (*L3: escape routing*). On this stackup L3 sits 0.19 mm above L4 and
   1.03 mm below L2, so its return reference is **L4**, not L2. The lines carve a
   channel through the L3 V5 pour, not a ground plane.
3. **USB D− reaches J2 on L3, through one via.** The U5 channel assignment
   (USB on pins 1/2, UART on pins 4/5, swapped in the schematic in
   `a80c933`) lets the pair reach the array without a crossing; both TVS stubs
   are on L1 (2.0 mm on D−, 1.5 mm on D+). From there D+ runs to J2 on L1,
   but D− drops through a via at (138.6, 110.75) and reaches B7 on L3. The
   via is where D− has to cross D+: J2's pin order is the reverse of U6's, so
   the crossing is topological and cannot be designed out on L1. At USB Full
   Speed it has no electrical effect. **Accepted 2026-09-23** — see the USB
   check below the checklist.
4. **CC2 passes under the USB-C body.** Three segments, all on L1, no vias
   (checked 2026-09-22). The USB4085 shell is metal and grounded, so
   soldermask is the only insulation between it and the trace. CC2 is a
   static pull-down strap, not a signal, and USB is used only for setup
   flashing. The shell's four soldered tabs are its only contacts with
   copper, and CC2 stays ≥1.45 mm from all of them (measured 2026-09-24).
5. **L4 carries the ten test pads.** They are bare copper with no BOM line —
   nothing is assembled on L4, so *single-sided assembly* holds — but each pad
   is a void in the L4 ground pour. L2 remains the unbroken plane the rules
   require, and L4 is the second return path, so this is accepted.
6. **Fiducials sit in the right-hand two-thirds only.** FID1 (151.6, 101.3)
   and FID2 (152.9, 120.5) either side of J1, FID3 (132.6, 111.1) mid-board:
   an asymmetric triangle ~20 × 19 mm. The only free L1 space at the left end
   is directly beside the antenna, and antenna keepout outranks fiducial
   spread. They are `serialtap:Fiducial_1mm_Mask2mm` (KiCad stock, copied
   in), board-only, and excluded from the BOM and the placement file.
7. **Two library footprints were trimmed to fit.** Silkscreen only, pads and
   keepouts untouched: three outline segments off `ESP32-C3-MINI-1` and four
   off `USB_C_Receptacle_GCT_USB4085`, to clear silk DRC. Made on the board,
   then written back to `lib/` so the library and the board agree.

## Pre-release review checklist

Items checked 2026-09-23 were measured from the board file (KiCad Python API
and `kicad-cli`), not read off the render. Notes follow the list.

- [x] Antenna keepout clear on **all four** layers, including pours
- [x] L2 ground plane unbroken end to end
- [x] Buck input loop contains no vias; ceramic within 2 mm of the IC
- [x] Switch node area minimised, not poured
- [x] Feedback trace clear of SW node and inductor (rerouted 2026-09-24 — see note)
- [ ] USB pair: no vias, no plane gap beneath, matched within 5 mm (one via on D− excepted — *Recorded exceptions* 3)
- [x] TVS sits ahead of series resistors, at the connector (distance to J1 excepted — *Recorded exceptions* 1)
- [x] Both VCCA and VCCB decoupled on every translator
- [x] No floating translator inputs
- [x] All test points present, labelled, accessible
- [x] 3 fiducials placed asymmetrically (2026-09-22 — see *Recorded exceptions* 6)
- [x] Silkscreen: 0.8 mm / 0.15 mm text, clear of pads and board edge
- [x] DRC clean at 5/5 mil, 0.2 mm (`kicad-cli pcb drc`)
- [x] `kicad-happy` PCB review clean: thermal vias, plane voids, trace width,
      impedance, DFM score (gate 2, 2026-09-24 — no blockers; triage below)
- [x] `kicad-happy` `pcbway` pre-order checklist passed (gate 3, 2026-09-24 — see below)
- [ ] Gerbers rendered and visually inspected before upload
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

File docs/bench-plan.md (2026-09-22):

# Bench plan — the AS50QDFHRA session

Everything the design is waiting on from the appliance, in one place. These
requirements had accumulated across the SPDD, three ADRs, `sim/README.md` and
the OEM board notes; this is the consolidated list, so nothing is discovered
missing after the unit is closed up again.

**Results from the 2026-09-16 session are in [bench-results.md](bench-results.md)** — the rail voltage and the logic levels are answered; the power tests are not.

**Write the predictions down first.** Each test below states what we expect. A
measurement that can only confirm is decoration; one that can refute is
evidence.

---

## Part 1 — Signals (Saleae)

Answers the harness. Does **not** answer anything in Part 2.

### 1.1 Pin mapping — ~~do this first~~ settled 2026-09-20

**No longer required.** The numbering was being read from the wrong end of the
connector. Corrected, and naming the signals from the **appliance's** side as
this document does, the order is 5 V, appliance RX, appliance TX, spare,
ground — which is what SPDD §5.2 calls 5 V, TX, RX, spare, GND from the
**board's** side, TX being the pin the board drives. Direction is fixed by the
working TinyS3 link (pin 2 ← TinyS3 TX, pin 3 → TinyS3 RX), not by inference. The continuity check below would now
only re-confirm it, and is kept for anyone repeating the work on another unit.

#### The check, as originally written

The OEM board exposes **gold test points marked `GEATX` and `GEARX`** on its
underside ([haier-oem-board.md](haier-oem-board.md)). With the unit powered
**off**, buzz continuity from each service-connector pin to those test points.

That turns pin identification from "infer it from which line talks first" into
a direct measurement, and takes two minutes.

Record: connector pin number → signal, for all five.
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

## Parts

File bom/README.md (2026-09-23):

# Sourcing and cost — checked 2026-09-20

Scope: **every line on the board**. The ten parts of SPDD §7.4 were checked on
2026-09-20; the passives were pinned and checked later the same day, once the
schematic fixed how many of each there are.

`bom.csv` is now **regenerated from the schematic**, so its `Reference` column
carries real designators instead of the old `U?`/`J?`/`C?` placeholders, and the
MPNs live in the symbol properties. The curated columns — distributor PNs,
stock, chosen distributor, notes — are merged forward by MPN, not regenerated.

**Every line now carries an MPN** — 22 lines, 33 components, **US$13.82/board**
at these prices. The switch line was settled on 2026-09-20 once the C&K
datasheet arrived by hand; it also forced R9 from 10 kΩ to 2.2 kΩ (SPDD §7.4).

## How this was checked

| Source | Method | Trust |
|---|---|---|
| LCSC | jlcsearch API, live query | Stock is live. **Price is indicative** — the API returns one figure, not a price ladder; LCSC's own ladder endpoint returned 404 |
| DigiKey | Product pages, live fetch | Stock and price ladder read directly off the product page |
| Mouser | **Checked by hand by the author** | Bot-blocked to automation. An API key was supplied 2026-09-20 and stored in `~/.config/secrets.env`, but Mouser rejects it as `Invalid unique identifier / API Key` — Search API keys sit in *pending authorization* after registration. Retry once it activates |
| Newark / element14 / Arrow | Not reached | All three refused automated access (403 / timeout) |

A `MOUSER_SEARCH_API_KEY` is now stored in `~/.config/secrets.env` (mode 0600,
outside this repo — it must never be committed), but is **not yet working**:
Mouser returns `Invalid unique identifier / API Key` on both the keyword and
part-number endpoints. The key is well-formed, so this is almost certainly
Mouser's registration approval still pending.

DigiKey has no credentials at all. Setting `DIGIKEY_CLIENT_ID` and
`DIGIKEY_CLIENT_SECRET` alongside a working Mouser key would make this whole
check a script rather than a one-off scrape — worth doing before the next
stock re-check, since stock data goes stale fast.

## The passives, pinned 2026-09-20

Searched by MPN against the jlcsearch API, because free-text search on that API
returns nothing — which suits this project anyway: the part is chosen first and
then checked for stock, never picked *because* it was in stock.

| Line | Refs | MPN | LCSC stock | US$ ea |
|---|---|---|---:|---:|
| 330 Ω 1% 0603 | R1, R2 | RK73H1JTTD3300F | 3,017 | 0.0051 |
| 5.1 kΩ 1% 0603 | R3, R4, R8 | RK73H1JTTD5101F | 13,741 | 0.0076 |
| 10 kΩ 1% 0603 | R10 (R9 was 10 kΩ until it moved to 2.2 kΩ, 2026-09-20) | RK73H1JTTD1002F | **1,192** | 0.0038 |
| 66.5 kΩ 1% 0603 | R5 | RK73H1JTTD6652F | 2,192 | 0.0154 |
| 100 kΩ 1% 0603 | R6, R7 | RK73H1JTTD1003F | 11,115 | 0.0043 |
| 100 nF 50 V X7R 0603 | C1, C7, C8, C9 | CL10B104KB8NNNC | 268,519 | 0.0115 |
| 1 µF 25 V X7R 0603 | C2, C3, C11 | CL10B105KA8NNNC | 178,930 | 0.0218 |
| 10 µF 25 V X7R 1206 | C5, C10 | CL31B106KAHNNNE | 30,509 | 0.2660 |
| 22 µF 25 V X7R 1210 | C6 | CL32B226KAJNNNE | 30,185 | 0.3599 |
| LED green 0603 | D1 | LTST-C191KGKT | 193,281 | 0.0217 |
| 2.2 kΩ 1% 0603 | R9 | RK73H1JTTD2201F | 1,033 | 0.0045 |
| Tact switch | SW1, SW2 | KMR211NGLFS | 8,125 | 0.6362 |

**The thinnest lines are the 2.2 kΩ at 1,033 and the 10 kΩ at 1,192** — about 100 boards' worth, and the
only passive under 2,000. Several other 10 kΩ 0603 1% parts showed absurdly low
stock in this index (Yageo RC0603FR-0710KL at 22, Panasonic ERJ-3EKF1002V at 2),
which is much more likely to be a partial index than the real LCSC position.
**Treat passive stock figures here as indicative only** — Mouser's API still
rejects its key, so there was no second source to cross-check against, and
DigiKey has no credentials at all.

**Datasheets are in [lib/datasheets](../lib/datasheets/)** for every pinned
passive. Samsung's own site and C&K's both refuse automated fetches; the Samsung
sheets came from a Future Electronics / Octopart mirror, and **the C&K one could
not be fetched at all**, which is why SW1/SW2 is still open.

## Every line is obtainable — but no single distributor can fill the board

| Part | DigiKey | Mouser | LCSC | Order from |
|---|---|---|---|---|
| TPS62162DSGT buck | 6,663 | — | 349 | LCSC |
| XGL4020-222MEC inductor | 3,876 | — | 5,408 | LCSC |
| B05B-XASK-1-A JST | 5,457 | — | 4,064 | DigiKey |
| TXU0204RUTR translator | 767 | — | 301 | DigiKey |
| **TPS2553DBVR eFuse** | **0** | **882** | **44,248** | **LCSC** |
| LM66200DRLR OR | 83,454 | — | 26,447 | DigiKey |
| TPD4E05U06QDQARQ1 ESD | 77,999 | — | **sample only** | DigiKey |
| USB4085-GF-A USB-C | 72,058 | — | 2,167 | DigiKey |
| **PCL1A471MCL1GS bulk** | **0** (24 wk, MOQ 500) | **69** | — | **Mouser** |
| ESP32-C3-MINI-1-H4X | **0** (4 wk, 3250 reel) | — | 911 | LCSC |

Three distributors, three shipments. **Three** lines are effectively
single-source — the eFuse is dual-sourced (LCSC and Mouser).

## The eFuse blocker is retired

SPDD §13 and CLAUDE.md both carry `TPS2553DBVR` availability as a live problem:
on 2026-09-19 only the `-1` latch-off variant — explicitly ruled out by ADR 0004
— could be found.

**The plain non-latching part is at LCSC as C55266, 44,248 in stock, ~$0.30.**
DigiKey is still out (3,000 arriving 2026-10-26), so the 2026-09-19 observation
was right about DigiKey and wrong only about the conclusion drawn from it.

**Mouser has it too: 882 in stock at A$1.60** (author-checked 2026-09-20). So
the part is genuinely dual-sourced, which matters more than the price gap —
LCSC is ~3× cheaper, but the Mouser order already has to happen for the bulk
capacitor, so the eFuse can ride along at no extra shipment if LCSC's stock
moves.

This takes the first of §13's three escape routes — *find the plain part at
another distributor* — so `TPS2552DBVR` and the `-1`-plus-auto-retry circuit are
both unnecessary. No design change, no library change.

One caveat: LCSC's auto-generated description for C55266 lists latch protection
among the features. That text is boilerplate for the whole TPS2553 family and is
not evidence about the suffix. **Check the package marking on receipt.**

## What is now the thinnest line

**PCL1A471MCL1GS, 69 pieces at one distributor.** Not a blocker, but it is the
only line with no second source and no depth:

- DigiKey stocks none — 24-week factory lead, 500-piece minimum (~US$456)
- LCSC does not list the part at all
- The sister part `PCR1E471MCL1GS` shows a 22-week lead and no stock at Arrow,
  so this is the series, not this one part number

Buy the spares in the same order. If that stock goes before the order does, the
fallback is a different 470 µF/10 V polymer — a substitution, which
[CLAUDE.md](../CLAUDE.md) says is proposed back and never applied silently.

Two other lines are single-source for reasons that are *choices*, not shortages:

- **TPD4E05U06QDQARQ1** — DigiKey only. LCSC has the `-Q1` solely as `-ES`
  engineering samples. The non-Q1 `TPD4E05U06DQAR` is everywhere and cheap, but
  §7.4 bought the `-Q1` for its temperature grade in a warm appliance
- **ESP32-C3-MINI-1-H4X** — LCSC only. The `H` (105 °C) and `X` (rev v1.1, since
  every non-X is NRND) are both mandatory; `-N4` is plentiful and is not a
  substitute

## Cost

Ten pinned parts, per board, cheapest in-stock source, USD:

| | Unit |
|---|---|
| ESP32-C3-MINI-1-H4X | 3.08 |
| PCL1A471MCL1GS | ~2.13 (A$3.25) |
| TPS62162DSGT | 1.50 |
| XGL4020-222MEC | 1.36 |
| TXU0204RUTR | 0.84 |
| TPD4E05U06QDQARQ1 | 0.79 |
| USB4085-GF-A | 0.77 |
| LM66200DRLR | 0.42 |
| TPS2553DBVR | 0.30 |
| B05B-XASK-1-A | 0.26 |
| **Subtotal, these ten** | **≈ US$11.46** |

The passives and switches bring the **whole board to ≈ US$13.82** (see the
top of this file); US$11.46 is the actives alone.

For 5 boards + 2 spares (7 pieces): **≈ US$80** in pinned parts — roughly
US$22 DigiKey, US$44 LCSC, US$15 Mouser.

Caveats, because these are estimates and not a quote:

- **Currency.** DigiKey and LCSC figures are USD as listed. The Nichicon is the
  author's Mouser AU figure, A$3.25, converted at an assumed ~0.66 — treat the
  conversion as approximate
- **Excludes** shipping, GST and duty. At this order size, shipping across three
  distributors to Australia will be a significant fraction of the parts cost,
  possibly more than it
- **Order 10, not 7, of the DigiKey lines.** DigiKey's qty-10 break means ten
  pieces cost about the same as seven at qty-1 pricing (≈US$31 vs ≈US$30). The
  extra spares are essentially free
- The Coilcraft inductor at DigiKey is a **Marketplace** listing: +US$10 flat
  shipping on its own. LCSC (5,408 in stock, cheaper) or Coilcraft direct avoids
  that — one reason it lands on LCSC above
- **Passives now counted** (2026-09-20): **US$1.09/board** at LCSC indicative
  pricing for the 21 pinned passive components (ten resistors, ten ceramics
  and the LED; the bulk capacitor is counted separately at US$2.13), of which the two 10 µF 1206 and
  the one 22 µF 1210 are US$0.89 — the ceramics dominate, and they dominate
  because they are 25 V X7R rather than the cheapest part that meets the value.
  The board total is **~US$12.55**, excluding the still-open switch line

The module and the bulk cap together are 45% of the board's parts cost. Nothing
here is worth optimising — [CLAUDE.md](../CLAUDE.md) principle 1 — it is
recorded because the number was asked for.

## For the PCBWay export

PCBWay turnkey sources by MPN, so `bom.csv` already carries what the quote
needs: MPN, manufacturer, and a distributor PN per line to disambiguate.

Two things to hand them explicitly, because they are the lines where a
well-meaning substitution would be wrong:

1. `TPS2553DBVR` — **not** `TPS2553DBVR-1`. The suffix is the whole decision
   (ADR 0004)
2. `ESP32-C3-MINI-1-H4X` — **not** `-N4`, **not** non-`X`, **not** `-1U`

Both belong in the order notes, not just the BOM.

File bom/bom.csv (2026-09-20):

Reference | Qty | Value | Footprint | MPN | Manufacturer | DigiKey_PN | DigiKey_Stock | Mouser_PN | Mouser_Stock | LCSC_PN | LCSC_Stock | Chosen_Distributor | Unit_Price_USD | Price_Basis | Validated | DNP | Notes
C4 | 1 | PCL1A471MCL1GS | serialtap:CP_Elec_8x10 | PCL1A471MCL1GS | Nichicon | PCL1A471MCL1GS-ND | 0 | 647-PCL1A471MCL1GS | 69 |  | 0 | Mouser | 2.1300 | Mouser AU A$3.25 | no | no | SINGLE SOURCE, THIN. Mouser 69 in stock (user-checked 2026-09-20, A$3.25). DigiKey non-stock: 24-week lead, MOQ 500. Not listed at LCSC. Mouser PN unverified — 647- prefix assumed, confirm at order. Buy spares now
C6 | 1 | 22u | serialtap:C_1210_3225Metric | CL32B226KAJNNNE | Samsung Electro-Mechanics |  |  |  |  | C309062 | 30185 | LCSC | 0.3599 | LCSC indicative | no | no | Value and dielectric per TPS62162 datasheet; 25 V for bias headroom at 3.3 V
C1,C7,C8,C9 | 4 | 0.1u | serialtap:C_0603_1608Metric | CL10B104KB8NNNC | Samsung Electro-Mechanics |  |  |  |  | C1591 | 268519 | LCSC | 0.0115 | LCSC indicative | no | no | Murata GRM188R71H104KA93D is a drop-in second source, 318k in stock
C5,C10 | 2 | 10u | serialtap:C_1206_3216Metric | CL31B106KAHNNNE | Samsung Electro-Mechanics |  |  |  |  | C14860 | 30509 | LCSC | 0.2660 | LCSC indicative | no | no | 25 V part on a 5 V rail, chosen for DC-bias headroom (inference, not a vendor curve)
C2,C3,C11 | 3 | 1u | serialtap:C_0603_1608Metric | CL10B105KA8NNNC | Samsung Electro-Mechanics |  |  |  |  | C29936 | 178930 | LCSC | 0.0218 | LCSC indicative | no | no
D1 | 1 | LED | serialtap:LED_0603_1608Metric | LTST-C191KGKT | Lite-On |  |  |  |  | C125098 | 193281 | LCSC | 0.0217 | LCSC indicative | no | no | Vf 1.9-2.4 V gives ~0.6 mA through R8. Dim by design (SPDD 5.7). -55..+85 C
J1 | 1 | B05B-XASK-1-A | serialtap:JST_XA_B05B-XASK-1-A_1x05_P2.50mm_Vertical | B05B-XASK-1-A(LF)(SN) | JST | 455-B05B-XASK-1-A-ND | 5457 |  |  | C491708 | 4064 | DigiKey | 0.2620 | DK qty10 | no | no | Through-hole — needs the selective/hand-solder step
J2 | 1 | USB4085-GF-A | serialtap:USB_C_Receptacle_GCT_USB4085 | USB4085-GF-A | GCT | 2073-USB4085-GF-ATR-ND | 72058 |  |  | C7095263 | 2167 | DigiKey | 0.7720 | DK qty10 | no | no | Through-hole, shares the JST solder step
L1 | 1 | XGL4020-222MEC | serialtap:L_Coilcraft_XGL4020_4.0x4.0mm | XGL4020-222MEC | Coilcraft | 2457-XGL4020-222MEC-ND | 3876 |  |  | C6012410 | 5408 | LCSC | 1.3630 | LCSC indicative | no | no | DigiKey lists it as Marketplace: +$10 flat shipping, ~4 day. Coilcraft direct is the other option
R1,R2 | 2 | 330 | serialtap:R_0603_1608Metric | RK73H1JTTD3300F | KOA Speer |  |  |  |  | C160038 | 3017 | LCSC | 0.0051 | LCSC indicative | no | no | One KOA RK73H series across all five resistor values: 1%, 100ppm/degC, -55..+155 C
R5 | 1 | 66.5k | serialtap:R_0603_1608Metric | RK73H1JTTD6652F | KOA Speer |  |  |  |  | C2480277 | 2192 | LCSC | 0.0154 | LCSC indicative | no | no | RILIM. 1% is a TPS2553 datasheet requirement, not a preference
R6,R7 | 2 | 100k | serialtap:R_0603_1608Metric | RK73H1JTTD1003F | KOA Speer |  |  |  |  | C130231 | 11115 | LCSC | 0.0043 | LCSC indicative | no | no
R3,R4,R8 | 3 | 5.1k | serialtap:R_0603_1608Metric | RK73H1JTTD5101F | KOA Speer |  |  |  |  | C160048 | 13741 | LCSC | 0.0076 | LCSC indicative | no | no
R9 | 1 | 2.2k | serialtap:R_0603_1608Metric | RK73H1JTTD2201F | KOA Speer |  |  |  |  | C130233 | 1033 | LCSC | 0.0045 | LCSC indicative | no | no | Not 10k: sized so SW1 carries 1.5 mA, above C&K's 1 mA minimum contact current
R10 | 1 | 10k | serialtap:R_0603_1608Metric | RK73H1JTTD1002F | KOA Speer |  |  |  |  | C130232 | 1192 | LCSC | 0.0038 | LCSC indicative | no | no | Thinnest line of the new passives at 1,192 - still ~100 boards
SW1,SW2 | 2 | SW_Push | serialtap:SW_Push_1P1T_NO_CK_KMR2 | KMR211NGLFS | C&K (Littelfuse) |  |  |  |  | C221676 | 8125 | LCSC | 0.6362 | LCSC indicative | no | no | NG = no ground pin, per the C&K ordering key - fixes the footprint choice. Silver contacts, -40..+85 C
U1 | 1 | TPS2553DBV | serialtap:SOT-23-6 | TPS2553DBVR | Texas Instruments | 296-32464-1-ND | 0 | 595-TPS2553DBVR | 882 | C55266 | 44248 | LCSC | 0.2979 | LCSC indicative | no | no | NON-LATCHING part — NOT the -1. DigiKey out of stock, 3000 due 2026-10-26. Dual-sourced: Mouser also has 882 at A$1.60 (user-checked 2026-09-20), so LCSC price vs Mouser second source. Mouser PN unverified — 595- prefix assumed. Verify marking on receipt: LCSC's auto-generated description lists latch protection, which is family boilerplate, not this suffix
U2 | 1 | LM66200DRL | serialtap:TI_DRL0008A_SOT-5X3-8_2.1x1.6mm_P0.5mm | LM66200DRLR | Texas Instruments | 296-LM66200DRLRCT-ND | 83454 |  |  | C3235556 | 26447 | DigiKey | 0.4160 | DK qty10 | no | no | Both OR branches in one package
U3 | 1 | TPS62162DSG | serialtap:Texas_DSG0008A_WSON-8-1EP_2x2mm_P0.5mm_EP0.9x1.6mm_ThermalVias | TPS62162DSGT | Texas Instruments | 296-29897-1-ND | 6663 |  |  | C2863597 | 349 | LCSC | 1.5049 | LCSC indicative | no | no | DSGR (3000 reel) is $0.97 at LCSC / $1.86 DK qty1 — same die, reel size only
U4 | 1 | TXU0204RUT | serialtap:TI_RUT0012A_UQFN-12_2.0x1.7mm_P0.4mm | TXU0204RUTR | Texas Instruments | 296-TXU0204RUTRCT-ND | 767 |  |  | C5217875 | 301 | DigiKey | 0.8440 | DK qty10 | no | no | Thinnest stock of any line at both sources. RUT package only
U5 | 1 | TPD4E05U06DQA | serialtap:USON-10_2.5x1.0mm_P0.5mm | TPD4E05U06QDQARQ1 | Texas Instruments | 296-40696-1-ND | 77999 |  |  |  | 0 | DigiKey | 0.7930 | DK qty10 | no | no | DigiKey only. LCSC carries the -Q1 solely as -ES engineering samples (C19170925) — not orderable for a build. Non-Q1 TPD4E05U06DQAR is plentiful at LCSC but drops the temperature grade SPDD 7.4 bought
U6 | 1 | ESP32-C3-MINI-1 | serialtap:ESP32-C3-MINI-1 | ESP32-C3-MINI-1-H4X | Espressif Systems | 1904-ESP32-C3-MINI-1-H4XTR-ND | 0 |  |  | C41349510 | 911 | LCSC | 3.0795 | LCSC indicative | no | no | LCSC only. DigiKey non-stock: 4-week lead, 3250-piece reel. H = 105C grade and X = rev v1.1 are both mandatory (SPDD 7.4) — do not accept -N4 or a non-X substitution

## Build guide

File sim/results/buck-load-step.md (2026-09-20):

# buck-load-step

Generated by `sim/run.py` - do not edit; re-run instead.

| cout | vo_ss | vo_und | vo_ovr | margin | ok |
|---|---|---|---|---|---|
| 4.7e-06 | 3.2994 | 3.2846 | 3.3107 | 0.2846 | yes |
| 1e-05 | 3.2994 | 3.2905 | 3.3099 | 0.2905 | yes |
| 2.2e-05 | 3.2994 | 3.2926 | 3.3074 | 0.2926 | yes |

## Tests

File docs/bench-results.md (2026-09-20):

# Bench results — AS50QDFHRA, 2026-09-16

Measurements taken against the real appliance, answering
[bench-plan.md](bench-plan.md). **Session incomplete** — Part 2 (power) and the
pin-order confirmation were not reached.

Instrument: Saleae Logic Pro 8 `5701262AE78884C9`, Logic 2.4.46, driven by the
scripts in [`bench/`](../bench/). Instrument characterisation and calibration
are recorded in the bench plan; the short version is that channel-to-channel
mismatch is `3.083 mV/V × V − 11.714 mV` and is corrected for.

---

## Answered

### Rail voltage — bench-plan 2.1

**5.0257 V open-circuit**, 5.1 mV pk-pk, measured at the pin identified below as
the supply.

**The `TPD4E05U06` ESD array stays.** Its 5.5 V standoff has only 0.5 V of
margin over 5 V logic, and 2.1 set a threshold of ~5.25 V for reconsidering it.
At 5.03 V there is 0.47 V of margin. No change.

### Logic levels — bench-plan 1.3

The active signal line swings **−0.17 V to 5.17 V**. Logic high is the 5 V rail,
not 3.3 V.

**Level translation is required.** That prediction was listed as one that could
have removed a whole block from the design; it does not.

### Baud and framing on the active line — bench-plan 1.3

**230400 baud, 8N1.** Not 9600 8E1.

Evidence, from 311 clean pulses across six bursts over 180 s:

| Baud | Pulses shorter than one bit time | Mean deviation from integer bits |
|---|---|---|
| 9600 | **306 of 311** | 0.286 |
| 115200 | 140 of 311 | 0.202 |
| **230400** | **0 of 311** | **0.031** |

9600 is not merely a worse fit, it is impossible: almost every pulse on this
line is shorter than a single 9600 bit time. 460800 fits comparably well
because it is the harmonic — but of 290 matching multiples, 289 are even and
one is odd, which is what a 230400 signal looks like measured against a 2.17 µs
ruler. Framing is 8N1: see the independent review below — **88 of 88 frames**
across all captures carry a valid start and stop bit at 10 bits per frame;
11-bit framings validate 2–4 of 9. (An earlier figure of "67%" was the first
decoder's failure to resync between frames, not a property of the signal.)

---

## Independent review of the capture

Re-analysed from the raw edge lists the same day, by a second pass that
reconstructed the bitstream itself rather than reusing either decoder.

**The capture is sound.** Three captures on two independent sample clocks
(500 MS/s and 6.25 MS/s), threshold 1.2 V on a 5 V line. Eight bursts. Refit
from raw edges, the bit period is **4.326 µs → 231,158 baud**, 0.33% from
230400 and inside the 160 ns sample resolution. At 8N1 every burst decodes to
exactly 11 frames, **all 88 with a valid start and stop bit**, same bytes each
time. 11-bit framings fail. And a structural check nobody designed in: every
burst spans exactly **106.0 bit-times**, which is precisely where the last edge
must fall if the final byte is `E3` (`11100011` LSB-first — bits 5–7 and the
stop bit are high and merge into idle, so the last edge sits at 100+1+5).

**230400 8N1 is verified and stands.**

**"Not hOn" is two claims with different truth values:**

- *This heartbeat is not an hOn frame* — **true, and sourced.** The hOn
  transport frame is `FF FF <len> <flags> <5 reserved> <type> <data>
  <checksum> <crc16>`
  ([paveldn, protocol_overview.rst](https://github.com/paveldn/haier-esphome/blob/master/docs/protocol_overview.rst)).
  Ours has no `FF FF`, and none of sum8 / xor8 / ten common CRC-8 variants
  produce the last byte. Independently, hOn is **controller-polled** — odd
  request types from the module, even responses from the appliance — whereas
  this appliance transmits *unsolicited* every 30.004 s. Two mismatches, not
  one.
- *This appliance does not speak hOn* — **not established.** A listen-only
  capture of the unpaired idle state cannot show what the appliance does when
  a controller addresses it. The earlier withdrawal of this claim was correct.

**Prior art:** every documented ESPHome-on-Haier success is a `KZW-W001/W002`
or an `ESP32-for-Haier` module
([goral.net.pl](https://goral.net.pl/post/replacing-haier-wifi-modules/),
[HA thread](https://community.home-assistant.io/t/esp-haier-haier-air-conditioner-esp-home-wemos-d1-mini/127880),
[esphaier](https://github.com/MiguelAngelLV/esphaier)). **Nothing was found
for the Realtek `WCATA008` / `Combo_RTK_PP` generation.** That absence is not
proof, but it means there is no one to copy.

**One unsourced number:** the SPDD states hOn as 8E1. The ESPHome doc page
does not state parity and the component inherits it from the `uart:` block.
It is probably 8N1 (ESPHome's default) and "8E1" appears never to have been
sourced. Irrelevant to the above; relevant before FR-3 is cited again.

## What the traffic actually is

The active line carries a **fixed 11-byte message every 30 seconds**:

```
burst 1 @  11.460s   E2 BF 0B C0 A0 01 60 03 29 5B E3
burst 2 @  41.464s   E2 BF 0B C0 A0 01 60 03 29 5B E3
   ... six bursts at 30.004 s intervals, byte-for-byte identical
```

Two facts establish what this is:

1. **The OEM Wi-Fi module was not connected.** It was on the bench, upstairs,
   throughout every capture in this session.
2. **The setpoint was changed about 22 times during the 180 s capture** — 27 °C
   down to 16 °C one degree at a time, then back up — and the traffic did not
   change at all.

So the appliance is **polling for a module that is not there**, and reporting
state to nobody. It has no reason to narrate the setpoint when nothing is
listening. The second signal line being silent for the full 180 s fits: nothing
drives the appliance's RX because nothing is plugged in.

This is the connector SerialTap plugs into, and that message is very probably
**the poll SerialTap will have to answer**. Recorded here because it is the
first concrete thing known about the protocol.

### Two useful consequences

**The appliance does not broadcast state unsolicited.** Twenty-two setpoint
changes produced no traffic beyond the heartbeat. Firmware cannot expect to
learn the appliance's state by listening; it will have to ask.

**The bytes are provisional.** They decode consistently at 230400 8N1, but they
do not match the `FF FF` preamble the hOn protocol is documented to use. Either
the framing is not quite right, or this poll is not an hOn frame. Do not build
anything on these eleven bytes yet.

### What this does *not* mean

An earlier draft of this document concluded "this is probably not the hOn bus".
**That was not supported and has been withdrawn.** It rested on the setpoint
changes not appearing in the traffic — which has a simpler explanation that
requires nothing to be wrong.

**No hardware change follows from the baud finding.** SPDD FR-3 already
requires the design to "impose no design ceiling below 1 Mbaud"; 230400 sits
well inside that and the TXU0204 handles it with room to spare.

## What this means for the project — the critical path has moved

The SPDD scopes firmware as "configuring ESPHome's existing `haier`
component" and puts protocol work **out of scope**. That was a bet that the
component works on this unit. Today produced the first evidence against the
bet — wrong baud, wrong framing, wrong direction on the only line that talks,
and no prior art for this module generation — and no evidence for it.

**If the protocol on this port cannot be learnt, the power gate and the board
are moot.** A UART bridge with nothing to say is not a product. So the order
of work changes:

1. **Establish that the protocol is knowable** — before any further hardware
   investment, including the load test.
2. Only then the power gate, and fabrication behind it.

The hardware is not wrong. It is, for the moment, unproven to be *useful*.

## Observed pin behaviour

> **Numbering corrected 2026-09-20.** This session read the connector from the
> wrong end. Every number in this document is now the corrected one; old number
> *n* is new number *6 − n*. Nothing measured changed — the voltages,
> resistances and behaviours were taken against physical pins and stand as
> recorded. Only the labels were wrong.

Saleae channel *n* was clipped to connector pin *5 − n*; connector pin 5 was
used as the ground reference.

| Pin | Ch | Behaviour | Reading |
|---|---|---|---|
| 1 | 4 | **supply** — dead steady | 5.0257 V, 5.1 mV pk-pk |
| 2 | 3 | idle high, zero transitions in 180 s | 5.0114 V |
| 3 | 2 | **active** — full-swing traffic | −0.17 to 5.17 V |
| 4 | 1 | floating | no contact, or a genuine no-connect |
| 5 | — | ground reference | — |

The shape — one supply, two signals, one spare, one ground — matches SPDD
§5.2's expectation, and now so does the order.

**Direction is settled by a working link, not by inference** (2026-09-20). On
the TinyS3 rig in [gea3.md](gea3.md): pin 2 → HV2 → LV2 → TinyS3 **TX**, and
pin 3 → HV1 → LV1 → TinyS3 **RX**. Pin 2 is therefore the appliance's receiver
— which is why the bias network below sits on it — and pin 3 is its
transmitter. [bench-plan 1.1](bench-plan.md)'s continuity check to the OEM
board's `GEATX` / `GEARX` test points was never run and would now only
re-confirm this.

## DMM readings at the connector

Taken with the unit switched off, at the end of the session.

**Ground is pin 5 of the JST XA**, confirmed by continuity. This is the one
piece of the pin map that was measured rather than assumed at the time, and it
agrees with how the Saleae was clipped (channel *n* to pin *5 − n*), so the
channel mapping in the table above holds at least at that end.

**RX pin 2 was measured on the 20 kΩ range:**

| Meter probes | Reading |
|---|---:|
| black pin 5 (GND) → red pin 2 (RX) | 5.84 kΩ |
| black pin 2 (RX) → red pin 5 (GND) | 5.80 kΩ |
| black pin 2 (RX) → red pin 1 (5 V) | 4.62 kΩ |
| black pin 1 (5 V) → red pin 2 (RX) | 4.62 kΩ |

The near-symmetry with probe polarity makes a passive bias network much more
likely than an ESD-junction reading. The two measured resistances imply an
approximate Thevenin resistance of 2.6 kΩ at the appliance RX input, with a
roughly 2.8 V open-circuit bias point on a 5 V rail.

**Design decision:** use **330 Ω, 1%** series resistors on both translated UART
lines. This is conservative for installation faults and keeps the translator's
output current well below its rated drive while remaining small compared with
the measured appliance network. The value is no longer a 100–330 Ω guess.

## The test to run next

**Plug the `WCATA008` back into the appliance and sniff pins 3 and 4 with it
running.** That captures the real conversation, both directions, at its real
baud. It is the only test that answers the question that now matters:

- `FF FF …` at 9600 → ESPHome `haier` is viable; the 230400 heartbeat is an
  unrelated idle-mode behaviour, and the project resumes as planned.
- 230400 with no `FF FF` → the protocol is not hOn. Then the question is
  whether it can be learnt from the module's traffic, and the SPDD's scope
  needs an ADR before anything else is spent.

If piggybacking the connector with the module fitted is impractical, the
fallback is below.

### Fallback: the module on a bench PSU

**Power the OEM Realtek module on a bench PSU and watch its five pins.** It is
already off the appliance and on the desk, so this needs no ladder and no
dismantling. It answers more than the continuity check would:

- **The module's baud, independently.** Whatever it transmits must match the
  appliance. If it is 230400, this session's measurement is confirmed from the
  other direction; if it is 9600, the analysis here is wrong and that needs to
  be known.
- **Which pin is the module's TX**, and therefore the appliance's RX.
- **The module's real current draw** — see below.

### It also measures the number the power design rests on

The 300–370 mA requirement is derived, not measured: the RTL8720CM's datasheet
Table 20 gives 450 mA at 3.3 V, referred through the OEM buck to ≈330 mA at 5 V
([haier-oem-board.md](haier-oem-board.md)). **The actual module, powered on a
bench supply, measures that directly.** It is the assumption underneath the
fabrication gate.

**Identify the pins with a DMM before applying anything.** 5 V into a signal pin
destroys the module. Ground is whatever has continuity to the shield can; the
5 V pin reads through to the input side of the `C136/C138/C139` bulk group.
Set the PSU to 5.0 V with an **800 mA** limit — the documented inrush is ~590 mA,
and a limit set too low will brown the module into a reboot loop.

---

## Not reached

| | Why it matters |
|---|---|
| **Part 2.2–2.3 — the V–I curve** | optional bring-up characterisation; `RILIM` is now set from inference under ADR 0007 |
| Behaviour in current limit (2.3) | the one result that could still force a design change |
| Sag under pulsed load (2.4) | confirms `RAPP` dynamically |
| RX pull-up (2.5) | **Complete:** measured on the powered-down unit; sets both UART series resistors to 330 Ω, 1% |
| ~~Pin order confirmation (1.1)~~ | **Settled 2026-09-20** without it: the numbering was read from the wrong end, and the TinyS3 rig fixes direction |
| Mechanical (Part 3) | mounting holes, connector placement |

The rail measurement needs the unit **powered on**; the continuity and pull-up
checks need it **off**. Doing power first and continuity last avoids a second
power cycle.

---

# Session 2 — 2026-09-19: two-way GEA3 confirmed

**The protocol is GE Appliances GEA3.** The heartbeat above decodes completely
against GE's public library, and an ESP32-S3 on the port, powered from pin 1,
received 64 ERDs in answer to a subscribe-all. Full decode, wiring, config,
ERD map and open items are in **[gea3.md](gea3.md)**. "Not hOn" is no longer
two claims: the appliance does not speak hOn, or smartAir2, at all.

Done this session, in order: heartbeat decoded (CRC seed `0x1021` over
destination..payload, ERD read request for `0x6003` from `0xC0` to `0xBF`);
smartAir2 and USB ruled out on the existing capture; TinyS3 + BSS138 shifter
wired to pins 1/2/3/5 (corrected numbering); flashed with esphome-gea; plugged in; discovery log
received over Wi-Fi.

Not done: the series-current measurement (bench-plan Part 2, still the
fabrication gate), the on-change publications, and the cold power-cycle test
for the boot anomaly recorded in gea3.md. The pin numbering is still
provisional; the roles are now confirmed by the fact that the conversation
worked.

**The critical path has moved back.** With the protocol known and public, the
power gate is once again the thing in front of fabrication.

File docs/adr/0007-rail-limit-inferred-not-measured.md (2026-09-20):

# 7. The appliance rail's current limit is inferred, not measured

Date: 2026-09-19

## Status

Accepted

Amends [ADR 0004](0004-current-limited-inrush.md) and demotes Part 2.2 and 2.3
of [bench-plan.md](../bench-plan.md) from fabrication gate to optional
bring-up characterisation.

## Context

[bench-plan.md](../bench-plan.md) Part 2 specifies loading the appliance's 5 V
service rail with switched power resistors to plot its current-voltage curve,
find its current limit, and observe what it does in limit. It is labelled "the
fabrication gate" and SPDD §12.1 step 2 treats it the same way.

That framing predates [ADR 0004](0004-current-limited-inrush.md). ADR 0004
chose a current-limited eFuse over a slew-rate-limited load switch precisely so
that inrush would be bounded by a resistor rather than by the bulk capacitance,
making the two independent knobs. The consequence nobody followed through: the
only design output of the whole load test is `RILIM`, a single resistor. A test
whose output is one resistor value cannot gate fabrication, because getting it
wrong costs a resistor swap on an assembled board, not a revision.

The test also carries real cost. It means deliberately driving an appliance's
service rail into current limit, with dissipating resistors, at the top of a
ladder, with some risk to the appliance's control board.

Three independent lines of evidence now bear on whether the rail can carry
SerialTap:

1. **Design intent.** The rail was built to feed the OEM `WCATA008` module,
   whose `RTL8720CM` is rated 450 mA at 3.3 V and 800 mA inrush, referred
   through the OEM's own buck to roughly 330 mA steady and 590 mA inrush at
   5 V ([haier-oem-board.md](../haier-oem-board.md)). SerialTap's C3 peaks
   lower, and its eFuse makes it gentler at plug-in than the board it replaces.
2. **Direct observation, 2026-09-19.** A TinyS3 has run from the rail, with
   Wi-Fi associated and transmitting, powered from pin 1 with no USB
   ([gea3.md](../gea3.md)). Whatever regulator that board carries, it is not a
   gentler load than SerialTap: same job, larger SoC. If it is a linear
   regulator, its draw from the 5 V rail is roughly 40% higher than
   SerialTap's buck would be for the same 3.3 V work. **Worth confirming from
   the TinyS3 schematic, because it strengthens this argument.**
3. **Simulation.** `sim/rail-sag` already showed that more bulk capacitance
   would not rescue a weak rail, so there is no design lever being declined.

Each of these is weaker than a measurement. Point 1 is a datasheet rating read
as design intent, two inferences deep. Point 2 is qualitative: nobody has yet
put a meter in series, so "it works" is not a number.

## Decision

**Do not run the resistor load test as a precondition for fabrication.** Set
`RILIM` from inference: above SerialTap's worst-case steady draw so it cannot
nuisance-trip, and below the OEM-implied floor of the rail's capability so the
board still limits before the rail does. Account for the TPS2553's limit
accuracy at both ends of its tolerance, not just nominal.

Fit the resistor, and correct it during bring-up if the board misbehaves.

## Consequences

- **Fabrication is no longer gated on a bench measurement of the rail.** The
  remaining gates are the project library, the passives, schematic capture and
  layout.
- **ADR 0004's claim weakens, and this is the real cost.** "The limit can be
  set deliberately below a *measured* appliance capability, so the board is
  provably polite to the rail" becomes politely designed against inferred
  limits. That is a reduction in rigour and is recorded as such rather than
  quietly dropped.
- **ADR 0004's named fault mode becomes more likely to appear at bring-up.**
  Current-limit foldback on a genuinely weak rail must be distinguished from a
  brownout, and we now go into bring-up without having seen what this rail does
  in limit.
- `RILIM` remains a deliberately reasoned value, not a guess, but its
  justification is now documentary rather than empirical.

## Reversal condition

Reinstate the load test if bring-up shows any of: the board failing to start on
a rising rail, the eFuse tripping in normal operation, or the appliance
resetting or faulting when SerialTap is plugged in.

## Still required, because all three are free or nearly so

1. **Series current measurement.** A meter in series with the 5 V lead to the
   TinyS3, on the 10 A jack. Idle and Wi-Fi peak. This is the first measured
   current in the project and it needs no added load and no resistors.
2. **Cold power-cycle test, twice, at the isolator.** The board needed a manual
   reset on its first power-up from the appliance on 2026-09-19 and that is
   unexplained ([gea3.md](../gea3.md)). It is the one observed symptom
   consistent with a marginal rail, and unlike the current limit it could
   genuinely change the design, because it concerns enable and reset timing on
   a rising rail.
3. **Pull-up measurement on the RX line**, bench-plan 2.5, with the unit off.
   **Complete:** RX pin 2 measured 5.84/5.80 kΩ to GND and 4.62 kΩ to 5 V,
   setting both series resistors to 330 Ω, 1% (see bench-results.md).

And when convenient, sag under a load step (bench-plan 2.4) **with the ESP32 as
its own load** rather than with resistors: Wi-Fi transmitting continuously,
both cores busy, LED at full brightness, stepped from idle, with the rail on
the calibrated Saleae analog channel and `bench/analyse_rail.py`. That answers
the pulsed-load question in firmware, with no dissipating parts and no rewiring
at the top of a ladder.

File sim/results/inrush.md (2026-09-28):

# inrush

Generated by `sim/run.py` - do not edit; re-run instead.

| ief | iapp | ispike | icharge | vjst_min | trise | qin | margin | ok |
|---|---|---|---|---|---|---|---|---|
| 0.15 | 0.25 | 0.2500 | 0.1500 | 4.9249 | 0.0168 | 0.0068 | 0.9249 | yes |
| 0.2 | 0.25 | 0.2500 | 0.2000 | 4.8853 | 0.0121 | 0.0069 | 0.8853 | yes |
| 0.25 | 0.25 | 0.2500 | 0.2500 | 0.1342 | 0.0095 | 0.0069 | -3.8658 | NO |
| 0.3 | 0.25 | 0.2500 | 0.2500 | 0.1338 | 0.0095 | 0.0069 | -3.8662 | NO |
| 0.351 | 0.25 | 0.2500 | 0.2500 | 0.1338 | 0.0095 | 0.0069 | -3.8662 | NO |
| 0.4 | 0.25 | 0.2500 | 0.2500 | 0.1338 | 0.0095 | 0.0069 | -3.8662 | NO |
| 0.449 | 0.25 | 0.2500 | 0.2500 | 0.1338 | 0.0095 | 0.0069 | -3.8662 | NO |
| 0.5 | 0.25 | 0.2500 | 0.2500 | 0.1338 | 0.0095 | 0.0069 | -3.8662 | NO |
| 0.75 | 0.25 | 0.2500 | 0.2500 | 0.1338 | 0.0095 | 0.0069 | -3.8662 | NO |
| 0.15 | 0.3 | 0.3000 | 0.1500 | 4.9250 | 0.0168 | 0.0068 | 0.9250 | yes |
| 0.2 | 0.3 | 0.3000 | 0.2000 | 4.8999 | 0.0121 | 0.0069 | 0.8999 | yes |
| 0.25 | 0.3 | 0.3000 | 0.2500 | 4.8628 | 0.0095 | 0.0069 | 0.8628 | yes |
| 0.3 | 0.3 | 0.3000 | 0.3000 | 0.1566 | 0.0078 | 0.0069 | -3.8434 | NO |
| 0.351 | 0.3 | 0.3000 | 0.3000 | 0.1562 | 0.0078 | 0.0069 | -3.8438 | NO |
| 0.4 | 0.3 | 0.3000 | 0.3000 | 0.1562 | 0.0078 | 0.0069 | -3.8438 | NO |
| 0.449 | 0.3 | 0.3000 | 0.3000 | 0.1562 | 0.0078 | 0.0069 | -3.8438 | NO |
| 0.5 | 0.3 | 0.3000 | 0.3000 | 0.1562 | 0.0078 | 0.0069 | -3.8438 | NO |
| 0.75 | 0.3 | 0.3000 | 0.3000 | 0.1562 | 0.0078 | 0.0069 | -3.8438 | NO |
| 0.15 | 0.5 | 0.5000 | 0.1500 | 4.9250 | 0.0168 | 0.0068 | 0.9250 | yes |
| 0.2 | 0.5 | 0.5000 | 0.2000 | 4.9000 | 0.0121 | 0.0069 | 0.9000 | yes |
| 0.25 | 0.5 | 0.5000 | 0.2500 | 4.8750 | 0.0095 | 0.0069 | 0.8750 | yes |
| 0.3 | 0.5 | 0.5000 | 0.3000 | 4.8500 | 0.0078 | 0.0069 | 0.8500 | yes |
| 0.351 | 0.5 | 0.5000 | 0.3510 | 4.8245 | 0.0066 | 0.0070 | 0.8245 | yes |
| 0.4 | 0.5 | 0.5000 | 0.4000 | 4.8000 | 0.0058 | 0.0070 | 0.8000 | yes |
| 0.449 | 0.5 | 0.5000 | 0.4490 | 4.7754 | 0.0051 | 0.0070 | 0.7754 | yes |
| 0.5 | 0.5 | 0.5000 | 0.5000 | 0.2462 | 0.0046 | 0.0070 | -3.7538 | NO |
| 0.75 | 0.5 | 0.5000 | 0.5000 | 0.2460 | 0.0046 | 0.0070 | -3.7540 | NO |

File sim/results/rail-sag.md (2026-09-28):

# rail-sag

Generated by `sim/run.py` - do not edit; re-run instead.

| iapp | tper | v5min | v5avg | iapp_avg | iapp_pk | margin | ok |
|---|---|---|---|---|---|---|---|
| 0.05 | 0.01 | 2.9504 | 2.9865 | 0.0500 | 0.0500 | -1.0496 | NO |
| 0.075 | 0.01 | 2.9624 | 3.0091 | 0.0750 | 0.0750 | -1.0376 | NO |
| 0.1 | 0.01 | 2.9716 | 3.0496 | 0.1000 | 0.1000 | -1.0284 | NO |
| 0.11 | 0.01 | 4.2537 | 4.5733 | 0.1094 | 0.1100 | 0.2537 | yes |
| 0.12 | 0.01 | 4.3163 | 4.6788 | 0.1076 | 0.1200 | 0.3162 | yes |
| 0.13 | 0.01 | 4.3579 | 4.7333 | 0.1066 | 0.1300 | 0.3579 | yes |
| 0.15 | 0.01 | 4.4379 | 4.7983 | 0.1054 | 0.1500 | 0.4379 | yes |
| 0.175 | 0.01 | 4.5313 | 4.8412 | 0.1045 | 0.1750 | 0.5313 | yes |
| 0.2 | 0.01 | 4.6156 | 4.8645 | 0.1039 | 0.2000 | 0.6156 | yes |
| 0.225 | 0.01 | 4.6875 | 4.8774 | 0.1035 | 0.2250 | 0.6875 | yes |
| 0.25 | 0.01 | 4.7373 | 4.8832 | 0.1034 | 0.2500 | 0.7373 | yes |
| 0.275 | 0.01 | 4.7424 | 4.8835 | 0.1033 | 0.2570 | 0.7424 | yes |
| 0.3 | 0.01 | 4.7424 | 4.8835 | 0.1033 | 0.2570 | 0.7424 | yes |
| 0.05 | 0.004 | 2.9504 | 2.9701 | 0.0500 | 0.0500 | -1.0496 | NO |
| 0.075 | 0.004 | 2.9624 | 2.9873 | 0.0750 | 0.0750 | -1.0376 | NO |
| 0.1 | 0.004 | 2.9716 | 3.0051 | 0.1000 | 0.1000 | -1.0284 | NO |
| 0.11 | 0.004 | 2.9748 | 3.0136 | 0.1100 | 0.1100 | -1.0252 | NO |
| 0.12 | 0.004 | 2.9778 | 3.0234 | 0.1200 | 0.1200 | -1.0222 | NO |
| 0.13 | 0.004 | 2.9807 | 3.0348 | 0.1300 | 0.1300 | -1.0193 | NO |
| 0.15 | 0.004 | 2.9861 | 3.0627 | 0.1500 | 0.1500 | -1.0138 | NO |
| 0.175 | 0.004 | 4.5143 | 4.7111 | 0.1652 | 0.1750 | 0.5143 | yes |
| 0.2 | 0.004 | 4.6128 | 4.7807 | 0.1633 | 0.2000 | 0.6128 | yes |
| 0.225 | 0.004 | 4.6867 | 4.8142 | 0.1623 | 0.2250 | 0.6867 | yes |
| 0.25 | 0.004 | 4.7372 | 4.8288 | 0.1619 | 0.2500 | 0.7372 | yes |
| 0.275 | 0.004 | 4.7423 | 4.8297 | 0.1619 | 0.2570 | 0.7423 | yes |
| 0.3 | 0.004 | 4.7423 | 4.8297 | 0.1619 | 0.2570 | 0.7423 | yes |
| 0.05 | 0.0022 | 2.9504 | 2.9525 | 0.0500 | 0.0500 | -1.0496 | NO |
| 0.075 | 0.0022 | 2.9624 | 2.9648 | 0.0750 | 0.0750 | -1.0376 | NO |
| 0.1 | 0.0022 | 2.9716 | 2.9743 | 0.1000 | 0.1000 | -1.0284 | NO |
| 0.11 | 0.0022 | 2.9748 | 2.9777 | 0.1100 | 0.1100 | -1.0252 | NO |
| 0.12 | 0.0022 | 2.9778 | 2.9809 | 0.1200 | 0.1200 | -1.0222 | NO |
| 0.13 | 0.0022 | 2.9807 | 2.9840 | 0.1300 | 0.1300 | -1.0193 | NO |
| 0.15 | 0.0022 | 2.9861 | 2.9899 | 0.1500 | 0.1500 | -1.0138 | NO |
| 0.175 | 0.0022 | 2.9925 | 2.9969 | 0.1750 | 0.1750 | -1.0075 | NO |
| 0.2 | 0.0022 | 2.9987 | 3.0039 | 0.2000 | 0.2000 | -1.0013 | NO |
| 0.225 | 0.0022 | 3.0049 | 3.0112 | 0.2250 | 0.2250 | -0.9951 | NO |
| 0.25 | 0.0022 | 4.7236 | 4.7479 | 0.2430 | 0.2500 | 0.7236 | yes |
| 0.275 | 0.0022 | 4.7404 | 4.7555 | 0.2427 | 0.2591 | 0.7404 | yes |
| 0.3 | 0.0022 | 4.7404 | 4.7555 | 0.2427 | 0.2591 | 0.7404 | yes |

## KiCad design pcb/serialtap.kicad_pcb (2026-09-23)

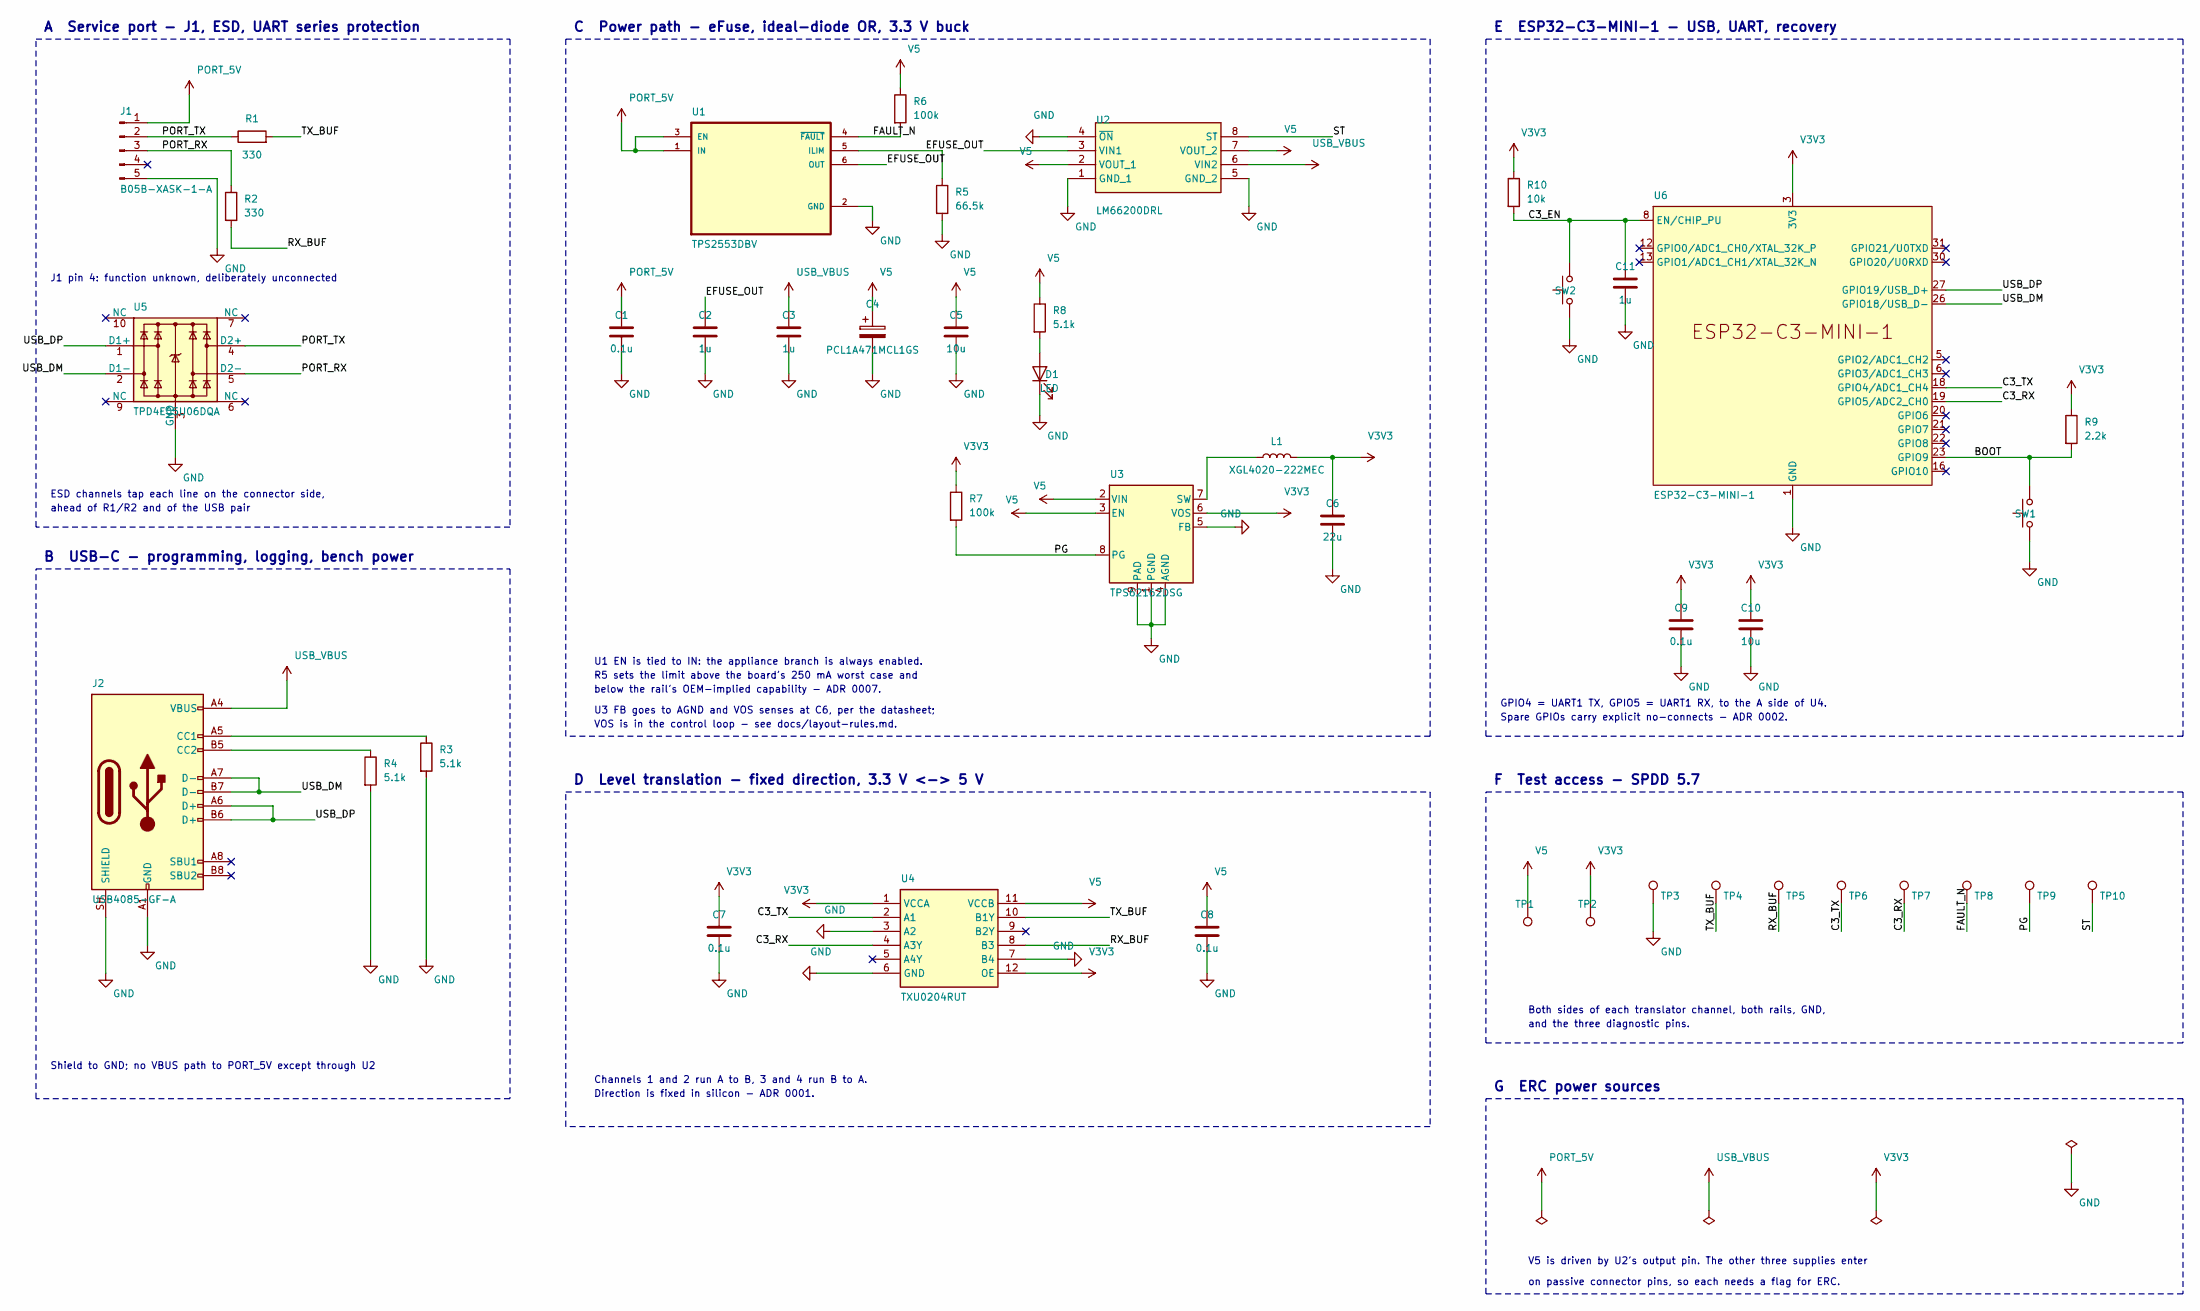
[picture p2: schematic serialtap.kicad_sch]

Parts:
C1, C7, C8, C9: 0.1u; C_0603_1608Metric; MPN CL10B104KB8NNNC
C2, C3, C11: 1u; C_0603_1608Metric; MPN CL10B105KA8NNNC
C4: PCL1A471MCL1GS; CP_Elec_8x10; MPN PCL1A471MCL1GS
C5, C10: 10u; C_1206_3216Metric; MPN CL31B106KAHNNNE
C6: 22u; C_1210_3225Metric; MPN CL32B226KAJNNNE
D1: LED; LED_0603_1608Metric; MPN LTST-C191KGKT
J1: B05B-XASK-1-A; JST_XA_B05B-XASK-1-A_1x05_P2.50mm_Vertical; MPN B05B-XASK-1-A(LF)(SN)
J2: USB4085-GF-A; USB_C_Receptacle_GCT_USB4085; MPN USB4085-GF-A
L1: XGL4020-222MEC; L_Coilcraft_XGL4020_4.0x4.0mm; MPN XGL4020-222MEC
R1, R2: 330; R_0603_1608Metric; MPN RK73H1JTTD3300F
R3, R4, R8: 5.1k; R_0603_1608Metric; MPN RK73H1JTTD5101F
R5: 66.5k; R_0603_1608Metric; MPN RK73H1JTTD6652F
R6, R7: 100k; R_0603_1608Metric; MPN RK73H1JTTD1003F
R9: 2.2k; R_0603_1608Metric; MPN RK73H1JTTD2201F
R10: 10k; R_0603_1608Metric; MPN RK73H1JTTD1002F
SW1, SW2: SW_Push; SW_Push_1P1T_NO_CK_KMR2; MPN KMR211NGLFS
TP1, TP2, TP3, TP4, TP5, TP6, TP7, TP8, TP9, TP10: TestPoint; TestPoint_Pad_D1.5mm
U1: TPS2553DBV; SOT-23-6; MPN TPS2553DBVR
U2: LM66200DRL; TI_DRL0008A_SOT-5X3-8_2.1x1.6mm_P0.5mm; MPN LM66200DRLR
U3: TPS62162DSG; Texas_DSG0008A_WSON-8-1EP_2x2mm_P0.5mm_EP0.9x1.6mm_ThermalV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; MPN TPS62162DSGT
U4: TXU0204RUT; TI_RUT0012A_UQFN-12_2.0x1.7mm_P0.4mm; MPN TXU0204RUTR
U5: TPD4E05U06DQA; USON-10_2.5x1.0mm_P0.5mm; MPN TPD4E05U06QDQARQ1
U6: ESP32-C3-MINI-1; MPN ESP32-C3-MINI-1-H4X

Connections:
/BOOT: R9.2, SW1.2, U6.23 (GPIO9)
/C3_EN: C11.1, R10.2, SW2.2, U6.8 (EN/CHIP_PU)
/C3_RX: TP7.1 (1_1), U4.4 (A3Y), U6.19 (GPIO5/ADC2_CH0)
/C3_TX: TP6.1 (1_1), U4.2 (A1), U6.18 (GPIO4/ADC1_CH4)
/EFUSE_OUT: C2.1, U1.6 (OUT), U2.3 (VIN1)
/FAULT_N: R6.2, TP8.1 (1_1), U1.4 (~FAULT)
/PG: R7.2, TP9.1 (1_1), U3.8 (PG)
/PORT_RX: J1.3, R2.1, U5.5 (D2-)
/PORT_TX: J1.2, R1.1, U5.4 (D2+)
/RX_BUF: R2.2, TP5.1 (1_1), U4.8 (B3)
/ST: TP10.1 (1_1), U2.8 (ST)
/TX_BUF: R1.2, TP4.1 (1_1), U4.10 (B1Y)
/USB_DM: J2.A7 (D-), J2.B7 (D-), U5.2 (D1-), U6.26 (GPIO18/USB_D-)
/USB_DP: J2.A6 (D+), J2.B6 (D+), U5.1 (D1+), U6.27 (GPIO19/USB_D+)
GND: C1.2, C2.2, C3.2, C4.2, C5.2, C6.2, C7.2, C8.2, C9.2, C10.2, C11.2, D1.1 (K), J1.5, J2.A1 (GND), J2.A12 (GND), J2.B1 (GND), J2.B12 (GND), J2.SH (SHIELD), R3.2, R4.2, R5.2, SW1.1, SW2.1, TP3.1 (1_1), U1.2 (GND), U2.1 (GND_1), U2.4 (~ON), U2.5 (GND_2), U3.1 (PGND), U3.4 (AGND), U3.5 (FB), U3.9 (PAD), U4.3 (A2), U4.6 (GND), U4.7 (B4), U5.3 (GND), U5.8 (GND), U6.1 (GND), U6.2 (GND), U6.11 (GND), U6.14 (GND), U6.36 (GND), U6.37 (GND), U6.38 (GND), U6.39 (GND), U6.40 (GND), U6.41 (GND), U6.42 (GND), U6.43 (GND), U6.44 (GND), U6.45 (GND), U6.46 (GND), U6.47 (GND), U6.48 (GND), U6.49 (GND), U6.50 (GND), U6.51 (GND), U6.52 (GND), U6.53 (GND)
unnamed: D1.2 (A), R8.2
unnamed: J2.A5 (CC1), R3.1
unnamed: J2.B5 (CC2), R4.1
unnamed: R5.1, U1.5 (ILIM)
unnamed: L1.1, U3.7 (SW)
PORT_5V: C1.1, J1.1, U1.1 (IN), U1.3 (EN)
USB_VBUS: C3.1, J2.A4 (VBUS), J2.A9 (VBUS), J2.B4 (VBUS), J2.B9 (VBUS), U2.6 (VIN2)
V3V3: C6.1, C7.1, C9.1, C10.1, L1.2, R7.1, R9.1, R10.1, TP2.1 (1_1), U3.6 (VOS), U4.1 (VCCA), U4.12 (OE), U6.3 (3V3)
V5: C4.1, C5.1, C8.1, R6.1, R8.1, TP1.1 (1_1), U2.2 (VOUT_1), U2.7 (VOUT_2), U3.2 (VIN), U3.3 (EN), U4.11 (VCCB)

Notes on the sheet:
D Level translation - fixed direction, 3.3 V <-> 5 V
Channels 1 and 2 run A to B, 3 and 4 run B to A.
below the rail's OEM-implied capability - ADR 0007.
U1 EN is tied to IN: the appliance branch is always enabled.
Spare GPIOs carry explicit no-connects - ADR 0002.
A Service port - J1, ESD, UART series protection
R5 sets the limit above the board's 250 mA worst case and
V5 is driven by U2's output pin. The other three supplies enter
on passive connector pins, so each needs a flag for ERC.
VOS is in the control loop - see docs/layout-rules.md.
GPIO4 = UART1 TX, GPIO5 = UART1 RX, to the A side of U4.
C Power path - eFuse, ideal-diode OR, 3.3 V buck
and the three diagnostic pins.
F Test access - SPDD 5.7
Both sides of each translator channel, both rails, GND,
ahead of R1/R2 and of the USB pair
ESD channels tap each line on the connector side,
E ESP32-C3-MINI-1 - USB, UART, recovery
U3 FB goes to AGND and VOS senses at C6, per the datasheet;
Shield to GND; no VBUS path to PORT_5V except through U2
J1 pin 4: function unknown, deliberately unconnected
G ERC power sources
Direction is fixed in silicon - ADR 0001.
B USB-C - programming, logging, bench power

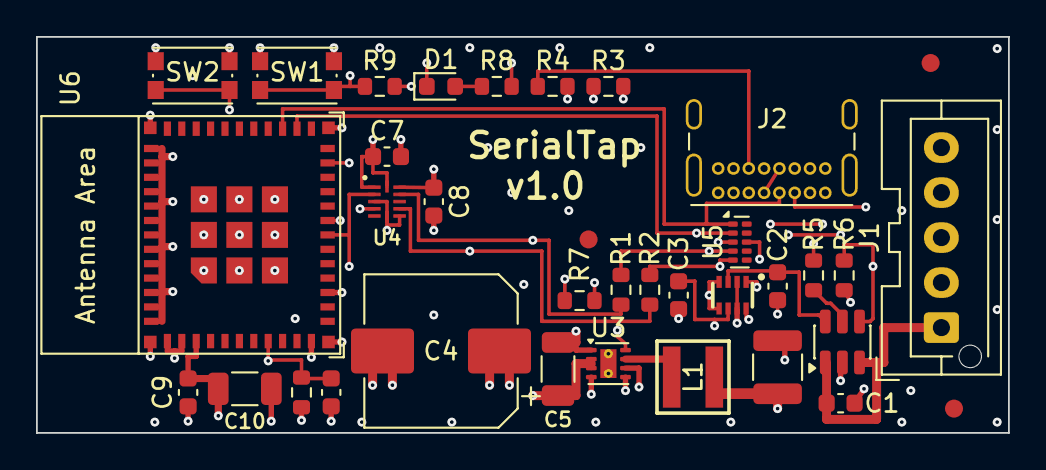
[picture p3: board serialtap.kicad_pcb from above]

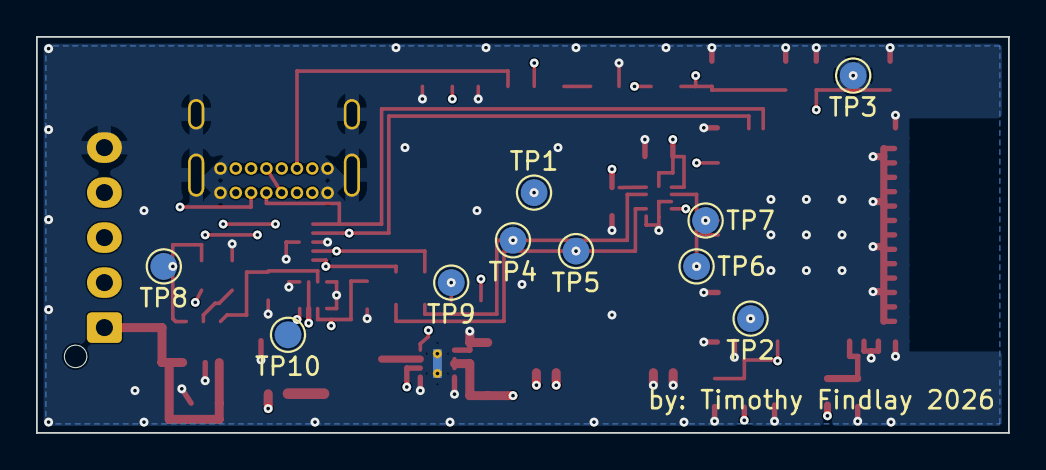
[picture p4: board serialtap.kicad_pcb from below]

Board: 4 copper layers, 54.0 x 22.0 mm, 46 parts (10 on the bottom side), 24 nets.

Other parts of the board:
FID1, FID2, FID3: Fiducial_1mm_Mask2mm

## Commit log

2026-09-12 Initial commit: design documentation and power-path simulation
    Design is documented but nothing is built. Carries the SPDD, the four
    ADRs, the layout rules, and the first two LTspice power-path decks.
    sim/ answers SPDD 5.8's first two questions:
    - rail-sag: sag is an average-current problem, not a peak-current one.
    470 uF is the right bulk value; more would not rescue a weak rail.
    - inrush: the eFuse limit must sit strictly below the appliance's own
    limit, which puts the appliance requirement at 300-370 mA rather than
    the 250 mA of SPDD 5.4.
    buck-load-step is deliberately absent. Its question is about the
    converter's control loop, which the behavioural blocks cannot answer,
    so it wa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
2026-09-12 docs: scope the vendor-SPICE-model rule to the buck only
    The inrush deck's question is answered by the eFuse's current limit
    alone, so requiring a vendor model there narrows the field for nothing.
    In exchange, current-limit accuracy becomes a first-order selection
    criterion - it is what turns the 300-370 mA appliance requirement into a
    single number.
    The rule still binds the buck, whose deck asks a control-loop question.
2026-09-12 elec: stub the board architecture; sim: add the TI buck model path
    elec/ fixes the block structure and how the blocks connect, and builds
    clean through atopile 0.15.9 into pcb/serialtap-r1p0/. No parts are
    pinned yet: instantiating bare passives would invite atopile's automatic
    part picker, which is the behaviour the project rules out, so passives
    arrive with their MPNs or not at all.
    Confirmed working end to end: ato build -> .kicad_pcb -> kicad-cli 10
    DRC (one violation, "no board outline", which is correct for a board
    with no layout yet).
    sim/ gains the vendor-model path for buck-load-step: fetch-models.sh
    downloads TI's unencrypted PSpice model (not redistributed) and
    pspice2ltspice.py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
    [serialtap-r1p0.kicad_pcb]
2026-09-12 port: the service connector is 5-pin XA, not 4
    Confirmed on the AS50QDFHRA, mated with a JST XARR-05V panel housing -
    XA series, 2.5 mm pitch. The series assumption held; the pin count did
    not.
    The board carries a 5-pin header so the harness can be straight-through,
    which is the least error-prone cable to build. Board-side candidates
    recorded in SPDD 5.2; not pinned yet, because entry direction is a
    mechanical call and the gender/mating relationship should be read off
    the JST datasheet rather than a distributor summary.
    The fifth pin connects to nothing - not the ESD array, not a GPIO -
    until its function is captured. Strapping an unknown signal, possibly
    not 5 V logic, to a net that matte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
    [serialtap-r1p0.kicad_pcb]
2026-09-12 pcb: add the KiCad project file and the 4-layer stackup
    atopile generates only a .kicad_pcb, and a default 2-layer one, so the
    board could not be opened as a project and contradicted SPDD 8. Both
    fixed by hand - the .kicad_pro and the stackup are hand-maintained
    files, not build artifacts.
    The project file carries the DRC values and net classes from
    docs/layout-rules.md. Verified they are actually enforced, not merely
    stored, by feeding kicad-cli a 0.05 mm track and confirming it was
    rejected against the 0.127 mm minimum.
    Four copper layers named per layout-rules.md. The dielectric heights are
    the usual nominal figures for a 1.6 mm four-layer board and are marked
    PROVISIONAL: layout-rules.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
    [serialtap-r1p0.kicad_pcb]
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2026-09-12 Add the licences the project already declared
    CERN-OHL-P v2 for the hardware, MIT for firmware and documentation -
    the split the docs have claimed since the first commit, with neither
    file present. A declared-but-absent licence quietly blocks the reuse
    this project exists to enable.
    LICENSE is the verbatim CERN-OHL-P v2 text fetched from CERN's
    canonical copy, not reproduced from memory. NOTICE says which licence
    covers which files, and records the third-party material under neither:
    vendor SPICE models, which fetch-models.sh downloads rather than
    redistributes, and any library assets sourced from vendors or SnapEDA.
    The copyright notice also goes in the schematic title block, so it
    appear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
    [serialtap-r1p0.kicad_sch]
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2026-09-13 pcb: outline 22 x 54 mm to drop into the OEM Haier board's place
    More area than the 40 x 25 it replaces (1188 vs 1000 mm2) and a longer
    axis to zone along, which helps the constraint that matters most -
    maximum distance between the buck's switch node and the module antenna.
    One rule had to change. layout-rules.md put both connectors on the same
    short edge; they do not fit across 22 mm. A 5-position XA header is
    ~14.6 mm and a USB-C receptacle ~8.9 mm, needing ~26 mm with edge
    clearance. The JST keeps the short edge because it carries the permanent
    harness and wants a clean cable exit; USB-C moves to the adjacent long
    edge, which costs nothing because it is bench-only and unused after
    first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
    [serialtap-r1p0.kicad_pcb]
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2026-09-13 port: pin B05B-XASK-1-A, with boss, tin
    The boss because this is the board's only permanent mechanical
    interface and absorbs every insertion force in a unit that vibrates -
    it carries that load into the board instead of the solder joints, for
    the price of one hole on a board with area to spare.
    Tin rather than -GU gold, and not to save money: plating should match
    across a mating pair, and standard XA crimp contacts are tin. Gold on
    one half only wears and promotes fretting, which is worse than a matched
    tin pair. If humidity later argues for gold it has to be both halves.
    -N is a packaging variant and irrelevant at five boards.
    Also records the assembly consequence: XA is through-hole, so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
2026-09-13 Close the buck load-step gate; pin TXU0204 for translation
    buck-load-step now runs on two vendor models with no stand-ins and
    passes with about 290 mV of margin: 3.2994 V regulated, 14 mV undershoot
    at worst on the 40 -> 335 mA step, against a 3.0 V brownout line. It
    passes at 4.7 uF as readily as at 22 uF, which settles the output
    capacitor - DC-bias derating cannot hurt us, so size it for ripple and
    stability rather than the load step.
    The undershoot is better than 22 uF on a 295 mA step deserves, implying
    the loop reacts within a switching cycle or two. DCS-Control is that
    fast, but this is TI's behavioural model, so the absolute figure is
    suspect. The conclusion is not: the margin would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
2026-09-13 Pin the eFuse and the ORing diodes; drop the PTC
    eFuse: TPS2553, the part ADR 0004 named. Constant-current limiting
    rather than the -1 suffix's latch-off, reverse blocking, thermal
    shutdown, SOT-23-6.
    RILIM is deliberately left unset. Its accuracy is worse at lower
    settings - the datasheet gives +/-9% at 520 mA but +/-15% at 130 mA -
    so the limit cannot simply be set as low as politeness would like. The
    choice trades nuisance-limiting against how much the appliance must
    supply, and ADR 0004 already ruled that this is a gated value rather
    than a guess. Wednesday's measurement sets it.
    ORing: LM66200, a dual ideal diode. Both branches in one package instead
    of two LM66100s, so the OR costs o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
2026-09-13 Pin the ESD array and the USB-C receptacle
    ESD: TPD4E05U06QDQARQ1, the part already familiar from previous work and
    a sound choice - quad, 0.5 pF, +/-12 kV, 2.5 A surge. Taking the -Q1 for
    its temperature grade rather than for automotive compliance, since this
    board sits in a warm appliance with no enclosure.
    One caveat recorded: its 5.5 V standoff leaves only 0.5 V of margin over
    5 V logic. Fine for a regulated rail, tight if the Haier's 5 V sits
    high, so the open-circuit rail voltage now matters for two reasons
    rather than one. It was already on the bench list.
    USB-C: GCT USB4085-GF-A, through-hole, horizontal top-mount, four
    retention posts, 10 000 mating cycles. Through-hole retention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
2026-09-13 Pin the bulk capacitor, and correct why this class was chosen
    Nichicon PCL1A471MCL1GS: 470 uF, 10 V, conductive polymer aluminium
    solid, 8 x 10 mm SMD. No liquid electrolyte means nothing to dry out,
    which is the real reason for a polymer part in a warm appliance.
    Tantalum was considered and set aside. Beyond cost, it is one of the 3TG
    conflict minerals - and note that Kemet POSCAP is tantalum-polymer, so
    it falls to the same objection despite the "polymer" name. Aluminium
    polymer avoids the issue entirely and is cheaper.
    Corrects SPDD 7.1's stated rationale. It justified polymer/hybrid on
    "far lower ESR, no dry-out". The ESR half does not survive contact with
    the numbers: the load step is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
2026-09-13 Pin the module: ESP32-C3-MINI-1-H4X
    4 MB flash is ample for an ESPHome image and OTA partitions with no
    filesystem to speak of, and the H grade's 105 C ambient is the right
    call for a bare board in an HVAC unit.
    Two things worth recording, because both are easy to get wrong.
    The U in -1U means a U.FL connector INSTEAD of an antenna, not as well
    as one. Since this design settled on the module's PCB trace antenna, the
    plain -1 is correct; -1U would arrive unable to transmit until an
    external antenna and pigtail were fitted inside the chassis.
    The X is not optional. It denotes chip revision v1.1, and every non-X
    variant is NRND in Espressif's own ordering table. daikin-esp uses the
    non-X ESP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
2026-09-13 docs: wiring, Kelvin sensing and resistor counts for the load test
    Spells out that the load and the probe both go ACROSS the rail. A
    breadboard holding the array is a good idea - nothing hot is held by
    hand - but the Saleae is a 1 Mohm voltmeter and nothing passes through
    it in series.
    Adds a second analog channel, because breadboard contact and rail
    resistance is 50-200 mOhm and at 400 mA that is 20-80 mV, against an
    expected droop of only 100-200 mV. Probing at both the connector and the
    load makes the rig's own drop a measured quantity rather than an
    unnoticed error in RAPP.
    Also notes the load must go on the pin confirmed to be the 5 V supply,
    not connector pin 5, which is the unknown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
2026-09-13 docs: define "load" and give the step sequence
    States plainly that the resistors are the load, since the term is
    ambiguous if you have not done this before, and says why an LED or a
    spare ESP32 will not substitute: the method gets current from I = V/R
    without an ammeter, which needs a component that actually obeys it. An
    ESP32 would also brown out under the conditions being measured, so the
    instrument would fail alongside the subject.
    Adds the concrete sequence for a 15 ohm 5 W part plus the seven 130 ohm
    resistors already to hand - 15R + 1 x 130R lands on 372 mA, just past
    the pass condition, in two components.
    Flags the trap: swap, do not stack. Adding the 15 ohm on top of all
    seven 130s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
2026-09-16 docs: independent review of the capture; protocol is now the critical path
    Re-analysed the three UART captures from raw edges rather than through either
    decoder. 230400 8N1 is verified: 4.326 us/bit, 88 of 88 frames with valid
    start and stop bits across two independent sample clocks, and every burst
    spans exactly the 106 bit-times a trailing 0xE3 predicts. The earlier "67%
    valid" was the first decoder failing to resync, not the signal.
    "Not hOn" is split into what the data supports and what it does not. The
    heartbeat is not an hOn frame - no FF FF separator, no matching checksum, and
    the appliance transmits unsolicited where hOn is controller-polled (sourced
    to paveldn's protocol overview).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
2026-09-19 docs: the protocol is GEA3 — decoded, then confirmed two-way on the appliance
    The 11-byte heartbeat from the 2026-09-16 capture decodes completely against
    GE Appliances' public tiny-gea-api: STX E2, dest BF, len 0B, src C0, ERD read
    request A0 for ERD 0x6003, CRC-16 seed 0x1021 over dest..payload, ETX E3. The
    earlier CRC-8 search failed because E3 is the end byte, not a checksum. The
    silkscreen's GEATX/GEARX was the clue.
    2026-09-19: a TinyS3 running esphome-gea, through a BSS138 shifter, powered
    from the appliance's own 5 V pin with no USB, sent subscribe-all and received
    64 ERDs with GE's public names. The heartbeat now arrives addressed to us and
    every re-subscription is answered. hOn,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
2026-09-19 docs: ADR 0006 protocol is GEA3, ADR 0007 rail limit inferred; unblock the gates
    Two decisions recorded, and a stale status block corrected.
    ADR 0006 — the reference appliance speaks GE Appliances GEA3, not Haier hOn.
    Decoded 2026-09-18 against GE's published tiny-gea-api, confirmed two-way on
    the appliance 2026-09-19 (64 ERDs returned, 28 of 28 subscribe-alls answered,
    no CRC errors). No hardware consequence, and it actively validates ADR 0001:
    GEA3 is full duplex with a fixed direction per line, whereas GEA2 in the same
    family is half duplex at 19200 and would have made fixed-direction translation
    the wrong topology. Firmware is no longer coupled to ESPHome or Home Assistant,
    because GE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
2026-09-19 lib: complete the library, adjudicating three footprints against vendor drawings
    Vendor CAD supplied by the author under import/ (gitignored, not part of the
    design). Where two sources disagreed, the vendor's own published land pattern
    decided it — which rejected two supplied footprints and repaired a third.
    STOP: TPS2553DBVR-1 is the wrong part. The -1 suffix is the latch-off variant,
    explicitly ruled out by SPDD §7.4 and ADR 0004, which chose this part for
    constant-current limiting. On overcurrent the -1 latches off and needs VIN or EN
    cycled to recover — inside an appliance, up a ladder. Worse, with 470 uF of bulk
    the plug-in charge time is the same order as the part's 8 ms fault de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
2026-09-19 sim: two decks were unrunnable; fix, correct the bulk ESR, re-run
    Started from the Nichicon datasheet and the TPS2553DBVR assets the author
    added, and found that rail-sag and inrush could not run at all in a clean
    checkout. The committed results were therefore not reproducible, and rail-sag's
    dated from before a change to the design it was supposed to model.
    Two defects, both pre-existing:
    - models/behavioral.lib was deleted by 786b8c3, which moved buck-load-step onto
    vendor models. It defines CLIM, IDEALD, CBULKX and BUCKLOAD — every block
    rail-sag and inrush are built from, and the eFuse model ADR 0004 points at.
    .gitignore carries an explicit !/models/behavioral.lib exception, s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
2026-09-19 bom: source every pinned part; the eFuse blocker is retired
    Checked all ten pinned parts of SPDD §7.4 against DigiKey (live product
    pages) and LCSC (jlcsearch API). Mouser, Newark, element14 and Arrow all
    refuse automated access; the two Mouser lines were checked by hand.
    TPS2553DBVR is no longer a blocker. The plain non-latching part is at LCSC
    (C55266, 44,248 in stock) and Mouser (882), so it is dual-sourced. DigiKey
    is still out until 2026-10-26 — the 2026-09-19 reading was right about
    DigiKey and wrong about the conclusion drawn from it. This takes the first
    of SPDD §13's three escape routes, so TPS2552DBVR and the -1-plus-auto-retry
    circuit are both moot. No design or library chang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
    [bom.csv]
2026-09-19 docs: record the sourcing result in SPDD and CLAUDE.md
    Both still carried TPS2553DBVR availability as a live problem, and CLAUDE.md
    still listed the distributor stock check as outstanding. Commit 222b53a made
    both wrong.
    SPDD §13: the eFuse open question is closed by its own first escape route —
    another distributor. The reasoning for rejecting the -1 is kept, since that
    still stands; what changes is only that we no longer need a fallback. Adds
    one goods-in check, because LCSC's listing text mentions latch protection and
    that is family boilerplate, not evidence about the suffix.
    SPDD §13 gains a new entry for PCL1A471MCL1GS depth — 69 pieces at a single
    distributor. Not a blocker, so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
2026-09-20 Capture the schematic, and correct the connector pin numbering
    Two things that turned out to be one commit, because splitting them would
    have left a snapshot where the schematic and the bench notes disagree about
    which pin is which.
    **The schematic is drawn.** `pcb/serialtap-r1p0.kicad_sch`, KiCad 10 native,
    one A3 sheet in seven blocks, 43 components and 57 nets, transcribed from the
    wiring contract in docs/schematic-capture.md. `kicad-cli sch erc
    --severity-all` reports 0 violations, and every review invariant was checked
    against the extracted netlist rather than the drawing — a drawing can look
    right and still be wrong.
    Decided at capture, with reasoning in docs/schematic-capture.md: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
    [serialtap-r1p0.kicad_sch]
2026-09-20 Pin every passive, and let the switch datasheet move a resistor
    Closes the last part-detail gate: all 22 BOM lines now carry an MPN, a
    footprint and a datasheet. ~US$13.82/board.
    Chosen as two families rather than line by line, because consistency is
    worth more here than per-line optimisation:
    - One KOA RK73H 1J series for every resistor value: 1%, 100 ppm/degC,
    -55..+155 C. The 66.5 kohm RILIM has to be 1% because the TPS2553
    datasheet says so, and running that grade everywhere costs cents and
    removes a class of mistake. Size code 1J = 0603 and tolerance code F =
    1% confirmed from the ordering table
    - One Samsung CL series for every ceramic, X7R only and >=25 V. The
    TPS62162's L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
    [bom.csv, serialtap-r1p0.kicad_sch]
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2026-09-21 Place and route r1p0, and fix three library defects on the way
    Netlist imported into the PCB, all 43 footprints placed inside the
    22 x 54 mm outline with the module's antenna keepout on-board (the slot
    is the whole envelope, so no overhang), and all 138 connections routed:
    signals and parts on L1, solid GND on L2, a V5 pour plus 3V3 traces on
    L3, GND on L4 with the ten test points as bare pads. DRC is clean apart
    from silkscreen warnings; zero unconnected, schematic parity zero.
    The TVS channel assignment was swapped in the schematic so the USB pair
    enters pins 1/2 and the UART pins 4/5 - the only order that routes the
    pair to the array without a crossing. Net-class patterns (Power, USB)
    no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
    [serialtap-r1p0.kicad_pcb, serialtap-r1p0.kicad_sch]
2026-09-22 Clear silkscreen DRC, add fiducials, and record the layout exceptions
    DRC is now clean: 0 violations, 0 unconnected, 0 schematic parity.
    Silkscreen: text minimums aligned to PCBWay's published capabilities
    (0.8 mm high, 0.15 mm stroke; the stroke rule was 0.12 mm, looser than
    the fab). U2 and U4 references resized; U4's small text came from the
    TXU0204 footprint in lib/, fixed at source. Silk tidied on the board,
    and the two footprints trimmed to do it (ESP32-C3-MINI-1, USB4085 -
    silkscreen only, pads and keepouts unchanged) written back to lib/ so
    the library and board agree.
    Three fiducials (serialtap:Fiducial_1mm_Mask2mm, KiCad stock copied
    in), board-only and excluded from BOM and plac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
    [serialtap-r1p0.kicad_pcb]
2026-09-22 Measure the USB pair against the layout rules, and correct two exceptions
    The pair was measured from the board file with KiCad's Python API.
    Length match passes (worst case 3.3 mm, ~4.7 mm with the via), but
    the checklist's no-via, no-plane-gap and 0.6 mm spacing items fail,
    and the geometry estimates ~105-110 ohm rather than 90. None of it
    matters electrically at USB Full Speed; recorded against the rule as
    written, pending an independent check before any reroute.
    Two recorded exceptions were wrong and are corrected: L3's return
    reference is L4 (0.21 mm), not L2; and the "TVS stub on L3" is D-'s
    connector leg through a via - both TVS stubs are on L1.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
2026-09-23 Move the USB pair's legs off the shell-tab reliefs, and accept the D− via
    Fix (a): both vertical legs moved 0.95 mm west (D+ 137.75 -> 136.80,
    D- 137.35 -> 136.40). D+ had lost L2 for 3.15 mm alongside J2's shell-tab
    thermal reliefs; it now has L2 beneath its whole length. The GND stitching via
    at (136.5, 106.0) sat on the new path and moved to (135.5, 106.0). Lengths
    unchanged; DRC 0 violations, 0 unconnected, 0 parity.
    Fix (b), landing D- on A7 on L1, cannot be done: J2's pin order reverses
    U6's, so D- must cross D+ once, and on one layer that crossing is a via. The
    only via-free route moves the layer change into J2's A6-B6 link at a cost in
    ground reference and spacing. The via is kept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
    [serialtap-r1p0.kicad_pcb]
2026-09-23 Work the pre-release checklist, and sense VOS at the output capacitor
    Checked from the board file: antenna keepout, L2 continuity, buck input loop,
    switch node, TVS order, translator decoupling and tie-offs, test points,
    silkscreen and DRC all pass, with measurements recorded in layout-rules.md.
    The one failure was U3's VOS line, which tapped L1's output pad and ran along
    the inductor body past the SW pad. Rerouted (by hand, in KiCad) to drop
    through a via to L3 and come up at C6's pad — the topology of TI's layout
    example, Figure 42 of the TPS62162 datasheet.
    missing_courtyard is now a DRC error rather than ignored: every footprint
    has one, and a future one without should not pass silen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
    [serialtap-r1p0.kicad_pcb]
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2026-09-23 Run review gate 3, and drill vias 0.2 mm to meet PCBWay's annular ring
    Checked against PCBWay's published capabilities. One real defect: every via
    was 0.25 mm drill on a 0.5 mm pad, a 0.125 mm annular ring, against PCBWay's
    0.15 mm via minimum. DRC could not catch it because the project's own rule
    was 0.125 mm. All 110 vias and U3's two thermal vias (board and lib/
    footprint) now drill 0.2 mm on the same pads, so no copper moves; the rules
    are now 0.2 mm min drill, 0.2/0.5 mm default via, 0.15 mm min ring. The
    0.55 mm-pad alternative was tried on a copy and left U5's pin-3 GND via
    0.004 mm too wide for its corridor. DRC 0 violations, 0 unconnected,
    0 parity. Fab class updated wherever the re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
    [serialtap-r1p0.kicad_pcb]
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2026-09-23 Rename the project to plain serialtap; git carries the version
    The KiCad files were pcb/serialtap-r1p0.kicad_*, with the revision in the
    file name by stated convention. Git already versions the design, so the
    suffix only duplicated it. The files are now pcb/serialtap.kicad_*, renamed
    with git mv so history follows.
    KiCad stores the project name inside its files too: 113 schematic instance
    entries, 43 PCB sheetfile references, three .kicad_pro entries, and a stray
    sheetfile in each of two lib/ footprints are all rewritten. The schematic's
    title-block Rev is cleared. Checked: ERC 0 errors and 0 warnings, DRC
    0 violations, 0 unconnected and 0 schematic parity, all 33 BOM parts still
    annotated,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
    [serialtap.kicad_pcb, serialtap.kicad_sch]
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

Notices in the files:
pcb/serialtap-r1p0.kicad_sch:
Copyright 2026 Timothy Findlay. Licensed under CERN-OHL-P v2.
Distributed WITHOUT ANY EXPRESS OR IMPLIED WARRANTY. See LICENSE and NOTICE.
